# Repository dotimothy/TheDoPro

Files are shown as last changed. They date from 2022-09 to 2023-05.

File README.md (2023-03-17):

# TheDoPro: A  Simplistic Stereovision Camera
## UC Irvine 2022-2023 Senior Design Project
Members: Timothy Do, Daniel Jilani, Zaya Lazar, Harrison Nguyen
<br>
Advisor: Professor [Glenn Healey](https://engineering.uci.edu/users/glenn-healey)
<br> 
<br>
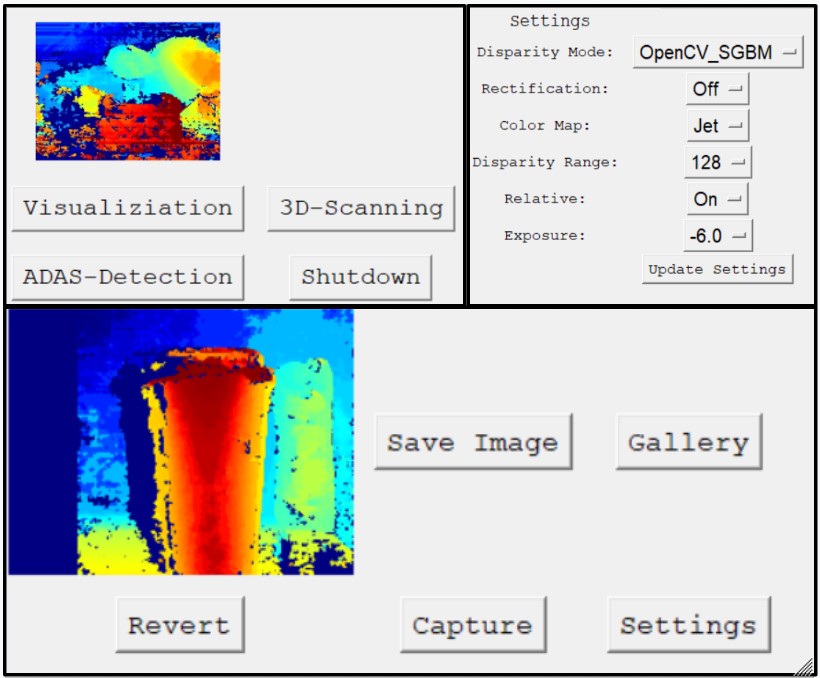
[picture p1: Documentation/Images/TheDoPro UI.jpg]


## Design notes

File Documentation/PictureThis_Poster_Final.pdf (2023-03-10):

# The Do-Pro: A Simplistic Stereo-Vision Camera

Timothy Do, Daniel Jilani, Zaya Lazar, Harrison Nguyen Professor Glenn Healey
Department of Electrical Engineering and Computer Science

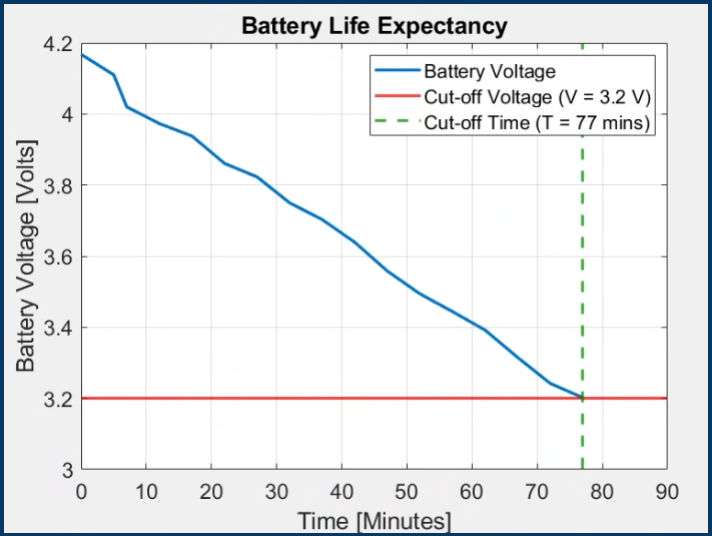
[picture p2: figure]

## Background

Humans have evolved with binocular vision to percieve depth [1]. This concept is applied to machines [2] in the form of SV, where two or more cameras take pictures of a scene and compute depth for technological applications. Some practical applications are 3-D scene reconstruction and Advanced Driving Assistance System (ADAS).

A simple SV camera is created by vertically aligning two embedded cameras separated by a baseline distance b and computing the disparity xL–xR between the two images captured by both cameras and mapping it to depth z (Fig. 1).

## Results

Hardware:
The Do-Pro was successfully assembled in its portable form factor. The battery life of the Do-Pro has a maximum expectancy of about 77 minutes (i.e., when the 3200 mAh battery drops from 4.2 V to 3.2 V).

Software:
The Do-Pro can generate relative visualizations of depth (Fig. 5). It was able to accurately measure depth from 1-4 feet with an accuracy of +/-1.5 inches (6% error). It can accurately reconstruct a 3-D point cloud and detect close-up objects around 1 feet away with 90% accuracy.

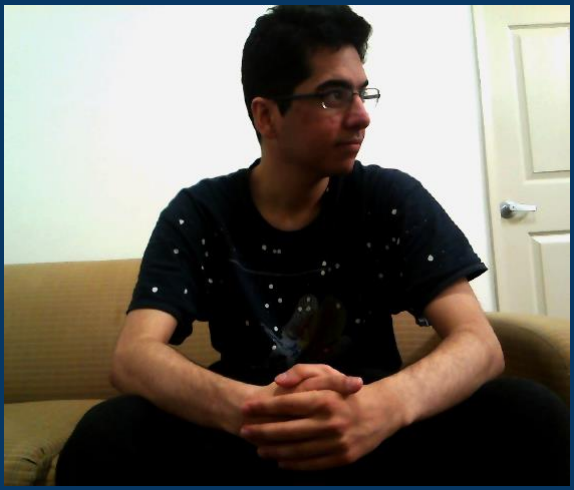
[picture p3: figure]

## References

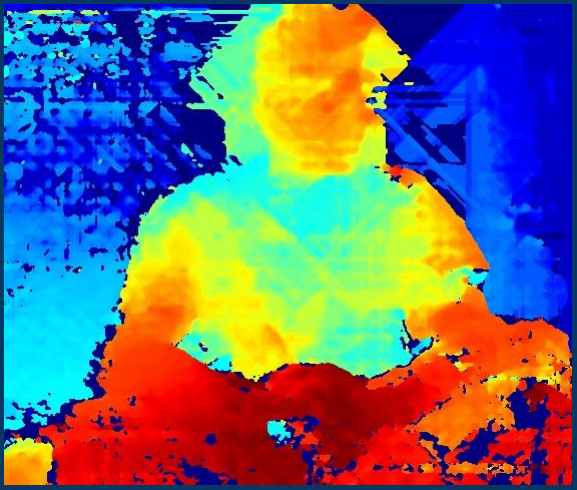
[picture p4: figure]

[1] F. Li (2014). Lecture 9 & 10: Stereo Vision. [PowerPoint]. Available: http://vision.stanford.edu/teaching/cs131_fall1415/lectures/lecture9_10_stereo_cs131. pdf
[2] B.K.P. Horn,, “Robot Vision”, Cambridge, MA: MIT Press, 1986, ch. 13.
[3] D. Scharstein, R. Szeliski and R. Zabih, "A taxonomy and evaluation of dense two-frame stereo correspondence algorithms," Proceedings IEEE Workshop on Stereo and
Multi-Baseline | Vision | (SMBV | 2001), | 2001, | pp. | 131-140, | doi:
10.1109/SMBV.2001.988771.

## Materials & Methodology

Hardware Design: 3-D Enclosure and Custom PCB
The 3-D enclosure replicates a digital camera for familiarity and ease of use. The custom PCB powers the cameras, buttons, LEDs, & touchscreen to a Raspberry Pi 4 using a boost converter topology with an 18650 battery cell (Fig. 2).

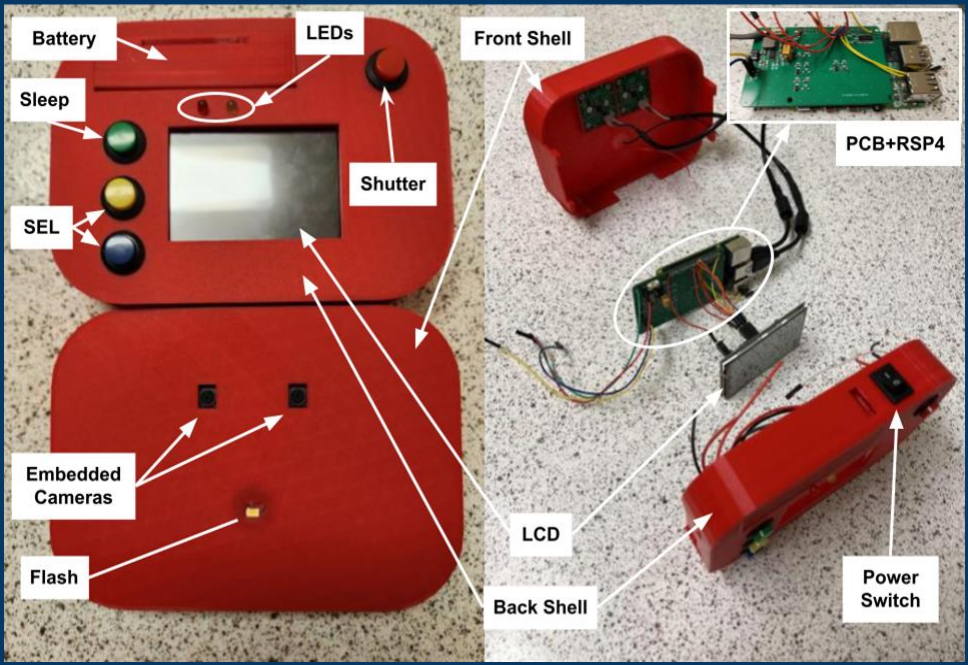
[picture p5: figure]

Software Design: User-Interface and Algorithms
The user interface (Fig. 3) was designed for configuring different visualizations of the disparity output. A specific rectification model was developed for calibrating the stereo pair. Multiple disparity algorithms [3] have been incorporated so users can tailor to their specific needs.

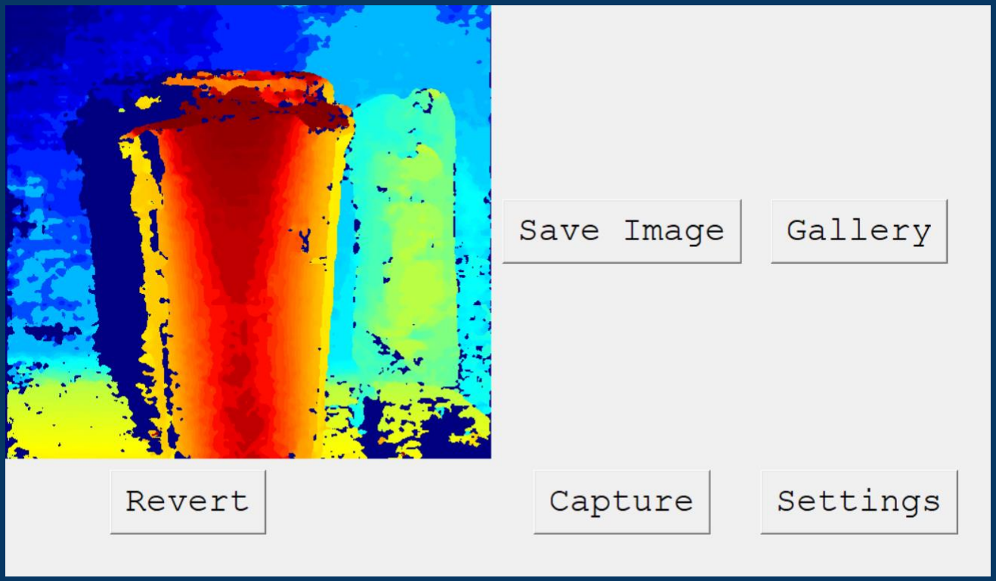
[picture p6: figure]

Applications: ADAS and 3-D Reconstruction
The Do-Pro can be used as an ADAS sysytem by K-Means clustering & segmenting the disparity output for detecting nearby objects. It can also be used for 3-D reconstruction by converting the disparity into depth to transform the scene into a point cloud.

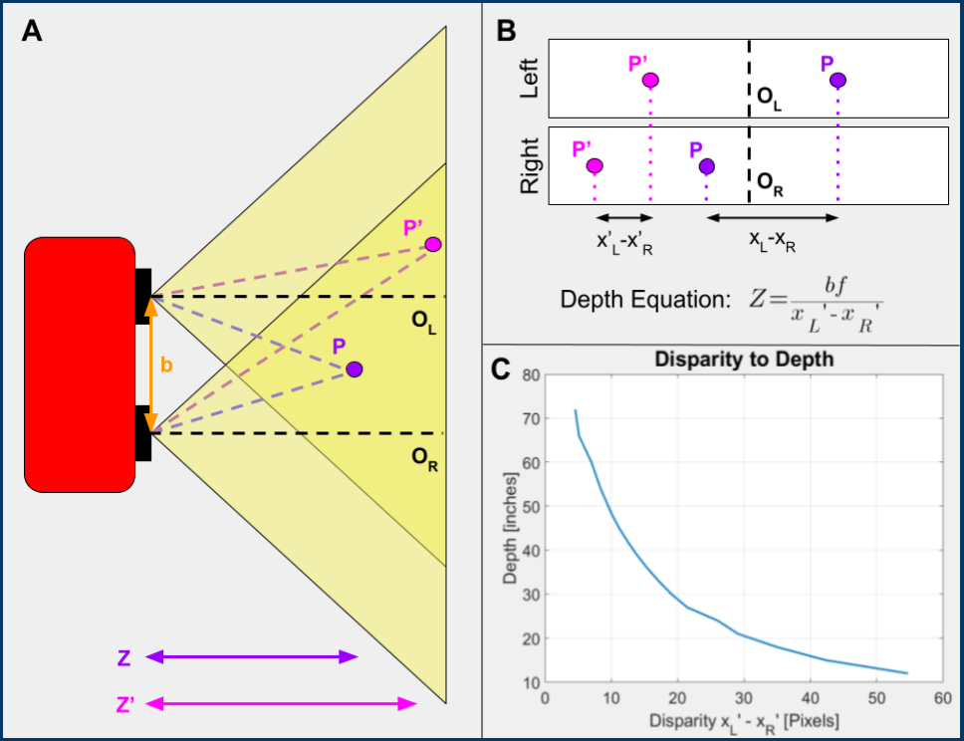
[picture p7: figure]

Figure 1. (A) SV camera imaging two scene points P and P’ located at depths Z and Z’ respectively. (B) Disparity between left and right images; closer scene points present greater disparities. (C) Empirically derived disparity to depth transform for the Do-Pro with a power regression model.

## Objectives

In this project, a portable stereo-vision (SV) camera, named The Do-Pro, was designed using off-the-shelf components to explore applications of depth perception. The Do-Pro aims to make SV technology more accessible and easy to use for unfamiliar scientists and hobbyists. The Do-Pro also provides a good introduction to computer vision and electrical engineering for K-12 students who are interested in STEM careers.

Figure 3. Touchscreen user interface and disparity of a coffee cup.

Figure 2. Components and connections of the camera.

Figure 4. Battery voltage under disparity computation load (~10 W).

Figure 5. Original image (left) vs. relative disparity map (right).

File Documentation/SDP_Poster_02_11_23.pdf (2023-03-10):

### Overview

Stereo vision is the extraction of depth in a scene from two or more images. In this project, an active stereo vision camera is designed with the ability to accurately extract depth from a scene for 3D-Scene Reconstruction and Object Detection.

### Deliverables

- Functional Stereo Vision Camera
- Active Stereo Implementation
- 3D Scene Reconstruction
- Object Detection System

### Background

Stereo vision cameras are specialized instruments designed to produce depth from at least two images. In active stereo vision, features are projected onto the scene which improves the disparity accuracy by making points in the scene more distinguishable.

### References

[1] D. Scharstein, R. Szeliski and R. Zabih, "A taxonomy and evaluation of dense two-frame stereo correspondence algorithms," Proceedings IEEE Workshop on Stereo and Multi-Baseline Vision (SMBV 2001), 2001, pp. 131-140, doi: 10.1109/SMBV.2001.988771.
[2] Q. Chang and T. Maruyama, "Real-Time Stereo Vision System: A Multi-Block Matching on GPU," in IEEE Access, vol. 6, pp. 42030-42046, 2018, doi: 10.1109/ACCESS.2018.2859445.
[3] F. Li (2014). Lecture 9 & 10: Stereo Vision. [Powerpoint]. Available: http://vision.stanford.edu/teaching/cs131_fall1415/lectures/lecture9_10_stereo_cs131.pdf

### Methodology

Hardware: Two embedded cameras are connected to a Raspberry Pi 4 for processing. A Custom PCB is used to connect the Pi, Buttons, LED, and LCD Touchscreen. Everything is housed within a portable 3D-printed enclosure.

Software: Several stereo matching algorithms are implemented for computing scene disparity with changeable parameters to control the disparity mapping.

# Project Progress

Hardware: | Software:

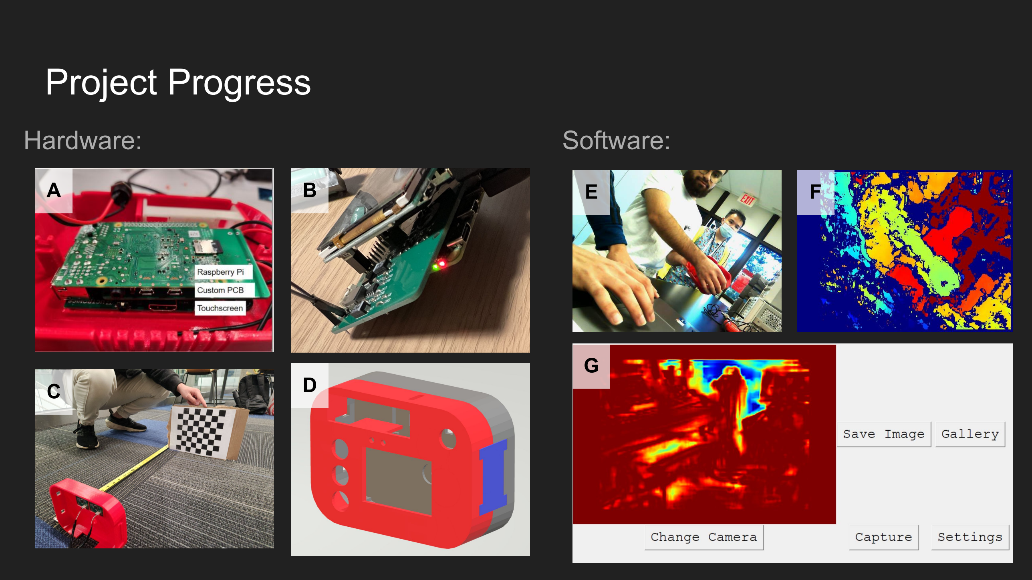
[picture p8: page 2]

A B

C D

E F

G

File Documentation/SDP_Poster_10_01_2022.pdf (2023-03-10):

# The Do-Pro: A Minimalistic Stereo Vision Camera

### Team: Timothy Do, Daniel Jilani, Zaya Lazar, Harrison Nguyen | Advisor: Dr. Glenn Healey

Background:

To perceive depth, two images of a scene must be observed at different points along a shared axis. Stereo vision cameras are specialized instruments designed to produce depth from at least two images. These cameras are specialized and expensive with state-of-the-art commercial cameras costing $500 and requiring a mount. In this proposal, we aim to produce a more affordable stereo vision camera designed for versatile applications.

A conceptual illustration of the proposed stereo vision camera. The camera is similar in style to most handheld digital cameras

Milestones:
- Milestone A - Develop simple stereo camera model and achieve functionality on breadboard
- Milestone B - Calibrate stereo-vision cameras
- Milestone C - Implement stereo vision processing, camera software mechanics, and PCB functionality Example of depth estimation on stereo vision image set.
S | F | W

Milestone A

| Milestone B
| Milestone C

Software Deliverable:

Hardware Deliverable:

High level wiring schematic of the proposed stereo vision camera system

References:
[1] A. Vij, “Stereo vision: How do 'terminators' see the world?,” Medium, 23-Mar-2021. [Online].
[2] B.K.P. Horn,, “Robot Vision”, Cambridge, MA: MIT Press, 1986, ch. 13.
[3] D. Scharstein, R. Szeliski and R. Zabih, "A taxonomy
and | evaluation | of | dense | two-frame | stereo
correspondence | algorithms," | Proceedings | IEEE
Workshop on Stereo and Multi-Baseline Vision (SMBV
2001), | 2001, | | pp. | 131-140, | doi:
10.1109/SMBV.2001.988771.

General Deliverables:
- Functional camera – 3D-printed chassis and manufactured PCB
- Auto-calibration
- Image & video Processing
- UI + touch screen + instruction manual
- ***Object tracking***

# Stereo-Vision Demonstration

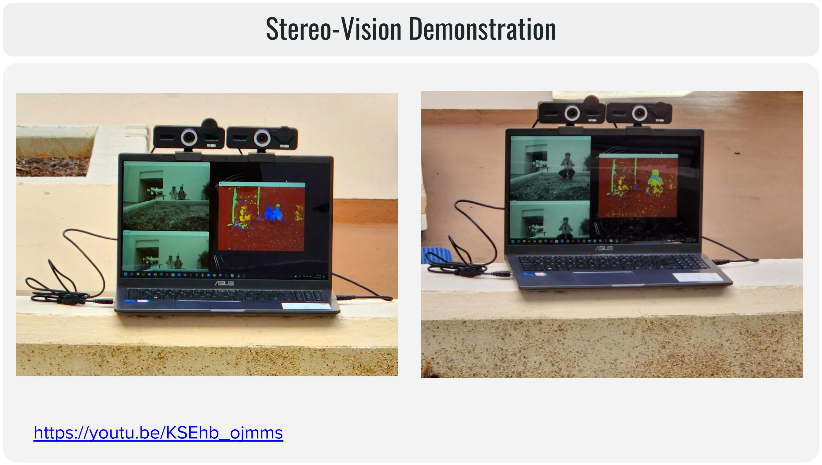
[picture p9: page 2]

# https://youtu.be/KSEhb_ojmms

# Estimated Expenses

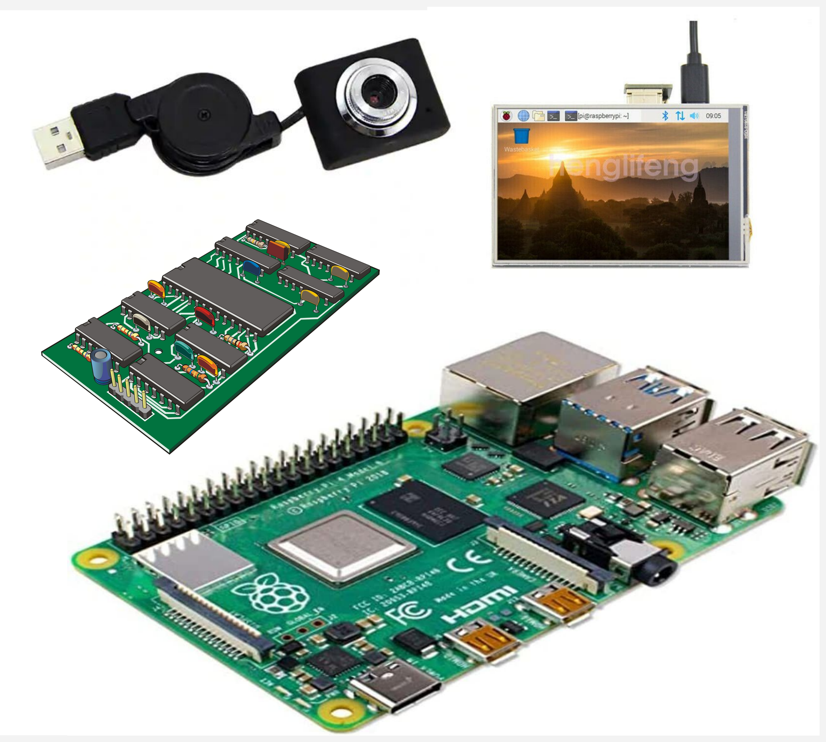
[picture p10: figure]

# Materials Expenses (Need to buy):

★ | Embedded Camera (x2) – $17.80
★ | Touchscreen Display – $36.99
★ | PCB Manufacturing – $25
★ | Miscellaneous Components – $18.04
★ | Vendors: Amazon, Digikey

# Required Expenses: ~$100

# Requested Funding: $175

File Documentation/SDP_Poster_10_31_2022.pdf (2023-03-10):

### Overview

Stereo vision is the analysis of depth in a scene from two or more images. For our project, we are designing a hand-held digital camera for stereo vision.

### Goals and Milestones

- Develop a compact stereo vision camera – as small as feasibly possible (Fall)
- Perform real-time stereo vision imaging for pictures and video (Fall)
- Utilize the camera for 3D printing and object tracking applications (Winter)

### Background

Stereo vision cameras are specialized instruments designed to produce depth from at least two images. These cameras are specialized and
expensive | with | state-of-the-art | commercial
cameras costing $500 and requiring a mount. In this proposal, we aim to produce a more affordable stereo vision camera designed for versatile applications.

### References

[1] D. Scharstein, R. Szeliski and R. Zabih, "A taxonomy and evaluation of dense two-frame stereo correspondence algorithms," Proceedings IEEE Workshop on Stereo and Multi-Baseline Vision (SMBV 2001), 2001, pp. 131-140, doi: 10.1109/SMBV.2001.988771.
[2] Q. Chang and T. Maruyama, "Real-Time Stereo Vision System: A Multi-Block Matching on GPU," in IEEE
Access, | vol. | 6, | pp. | 42030-42046, | 2018, | doi:
10.1109/ACCESS.2018.2859445.
[3] A. Islam, M. Asikuzzaman, M. O. Khyam, M. Noor-A-Rahim and M. R. Pickering, "Stereo Vision-Based 3D Positioning and Tracking," in IEEE Access, vol. 8, pp.
138771-138787, | 2020, | doi:
10.1109/ACCESS.2020.3011360.

### Methodology

Hardware: The hardware implemented consists of a custom PCB, Raspberry Pi, and two cameras in a 3D-Printed enclosure.

Software: The stereo matching algorithm described in [2] is implemented and vectorized for real-time computation of a image disparity map.

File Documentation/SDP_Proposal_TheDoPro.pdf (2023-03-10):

# The Do-Pro: A Minimalistic Stereo Vision Camera

# Proposed by Timothy Do, Daniel Jilani, Zaya Lazar, Harrison Nguyen

# Why care about depth?

# - In the near future, data will become one of the most important commodities in the world – industries and innovations will become significantly data-driven

# - Machine learning and image processing almost go hand-in-hand with significant applications in almost every field, such as autonomous vehicles

# - Creating a commercial camera that can segment an image into various depths will be highly valuable for machine learning applications in imaging

# - We want to generalize the technology and remove the need for specialized equipment

# Introduction

# - Cameras have become ubiquitous with various applications from iPhones to CC-TV cameras to dash cams

# - However, normal cameras by themselves do not have the capability to denote depth in an image

# - To quantify depth in an image, at least two cameras are required

# - Image processing methods exist to detect depth require complex models or very largely data-driven

- Lidar can be use in tandem with a camera to detect depth more accurately (i.e. iPhone XIV), but

# the technology is expensive

# Commercial Stereo Vision Cameras

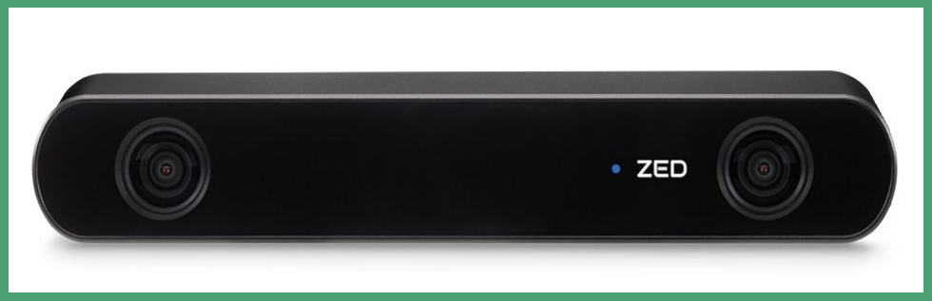
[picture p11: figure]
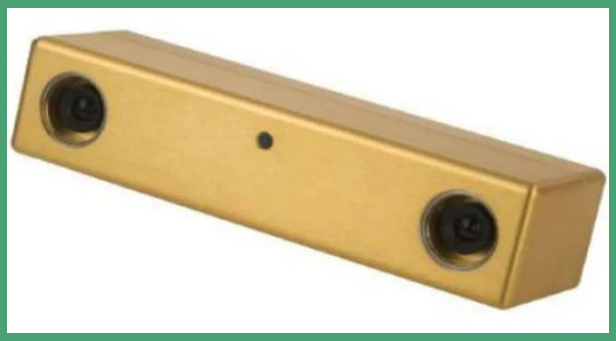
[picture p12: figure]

# - Bumblebee 2 / XB3

# - Discontinued - Varying price depending on seller

# - Zed 2

# - Price: $499 - State-of-the-art ■ Implements neural network for improved depth sensing and other spatial detection

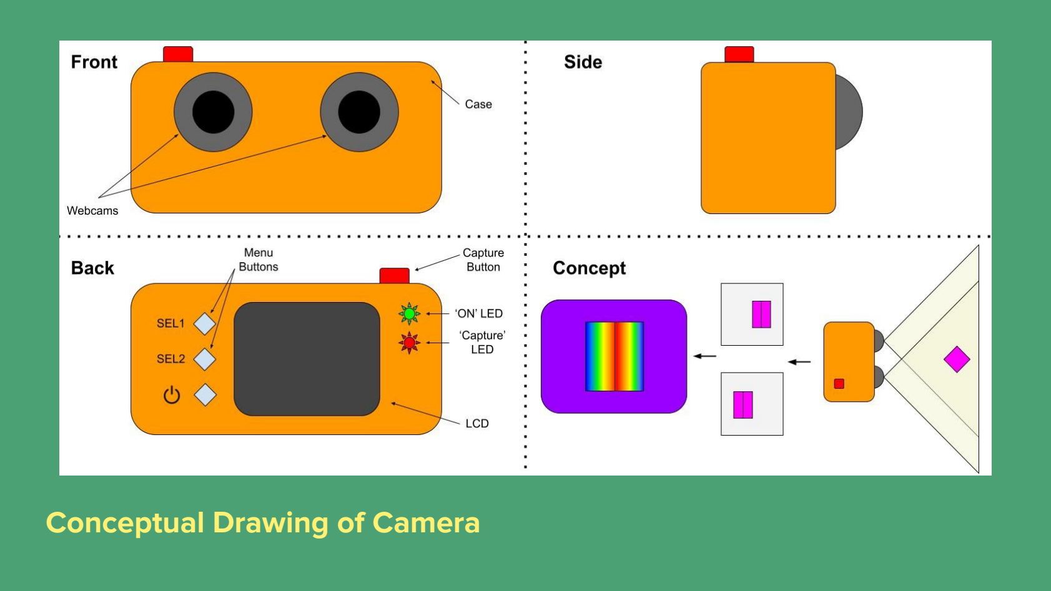
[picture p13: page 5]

# Conceptual Drawing of Camera

# Conceptual Design

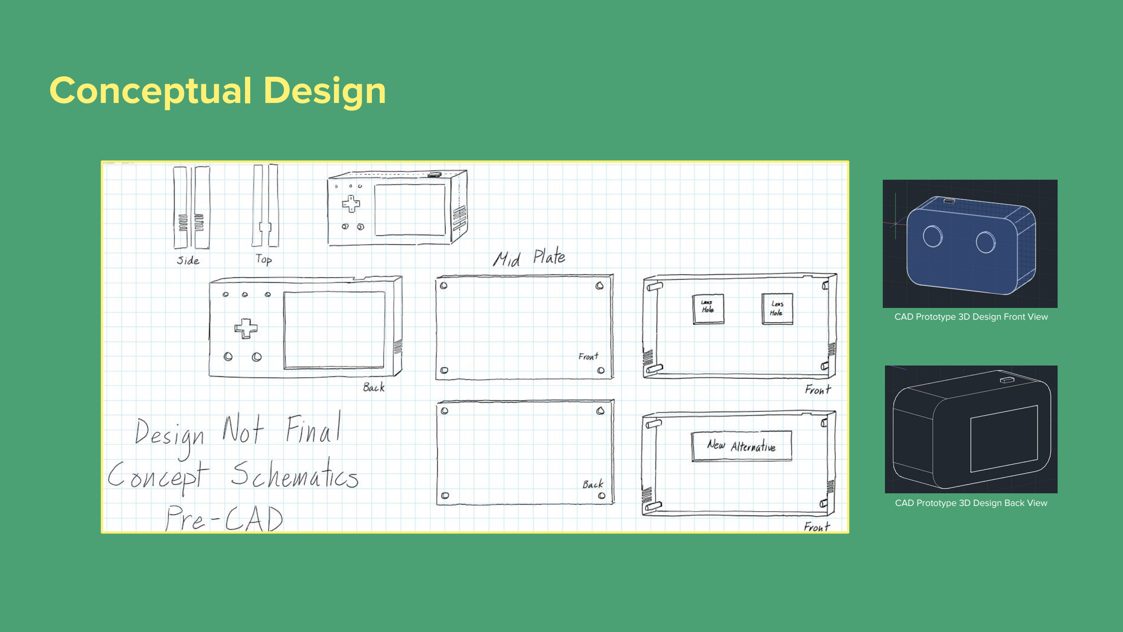
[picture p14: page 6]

CAD Prototype 3D Design Front View

CAD Prototype 3D Design Back View

# Concept Elaboration Updates

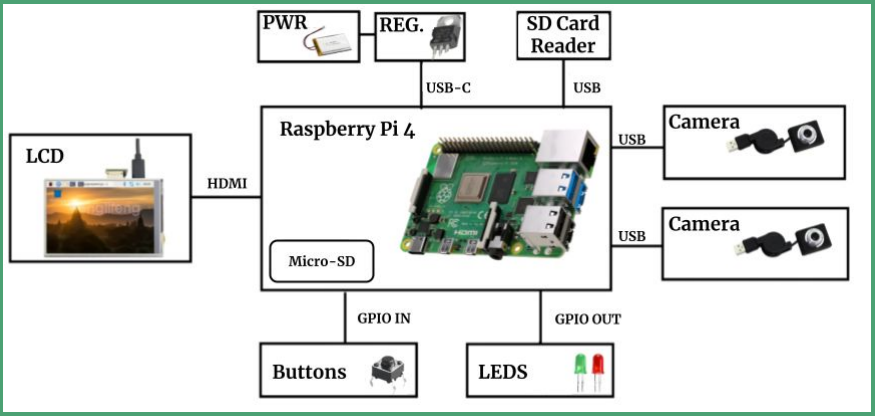
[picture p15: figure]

# High-level Wiring Schematic

# - Milestone A - Develop simple camera model

## - Design chassis for camera - Design wiring schematic for electronic components - Produce PCB and connect camera components - Test basic functionality - Optional: Adjustable distance between cameras

# - Milestone B - Calibrate stereo vision cameras

## - Test camera calibration outside of camera chassis - Implement camera calibration on raspberry pi with chassis - Implement procedure to calibrate cameras as a user function

# - Milestone C - Create depth heat map / 3D point cloud

## - In parallel with camera calibration, experiment with disparity map and 3D point cloud - Test display on LCD and create GUI

# Milestones

# Timeline

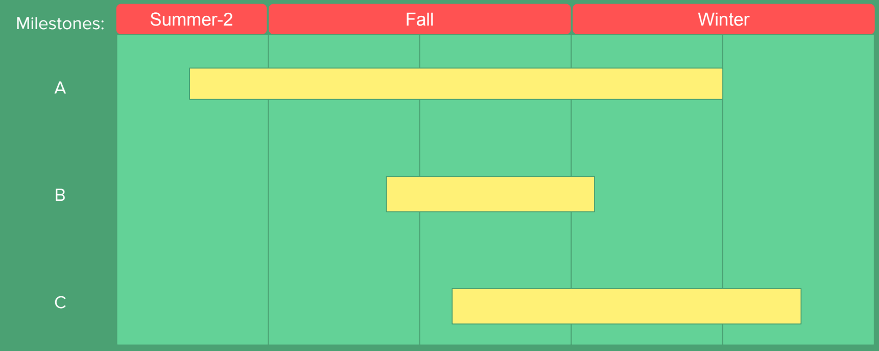
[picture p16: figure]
Milestones:; Summer-2; Fall; Winter

# Materials List

# - Regulator ICs - Various resistors and capacitors - Diodes - Fuse(s) - LCD Display - Custom PCB - Embedded Cameras (x2) - LEDs - Buttons - Capture Button - Raspberry Pi 4

# The Do-Pro: A Minimalistic Stereo Vision Camera

### Team: Timothy Do, Daniel Jilani, Zaya Lazar, Harrison Nguyen | Advisor: Dr. Glenn Healey

Background:

To perceive depth, two images of a scene must be observed at different points along a shared axis. Stereo vision cameras are specialized instruments designed to produce depth from at least two images. These cameras are specialized and expensive with state-of-the-art commercial cameras costing $500 and requiring a mount. In this proposal, we aim to produce a more affordable stereo vision camera designed for versatile applications.

A conceptual illustration of the proposed stereo vision camera. The camera is similar in style to most handheld digital cameras

Milestones:
- Milestone A - Develop simple stereo camera model and achieve functionality on breadboard
- Milestone B - Calibrate stereo-vision cameras
- Milestone C - Implement stereo vision processing, camera software mechanics, and PCB functionality Example of depth estimation on stereo vision image set.
S | F | W

Milestone A

| Milestone B
| Milestone C

Software Deliverable:

Hardware Deliverable:

High level wiring schematic of the proposed stereo vision camera system

References:
[1] A. Vij, “Stereo vision: How do 'terminators' see the world?,” Medium, 23-Mar-2021. [Online].
[2] B.K.P. Horn,, “Robot Vision”, Cambridge, MA: MIT Press, 1986, ch. 13.
[3] D. Scharstein, R. Szeliski and R. Zabih, "A taxonomy
and | evaluation | of | dense | two-frame | stereo
correspondence | algorithms," | Proceedings | IEEE
Workshop on Stereo and Multi-Baseline Vision (SMBV
2001), | 2001, | | pp. | 131-140, | doi:
10.1109/SMBV.2001.988771.

General Deliverables:
- Functional camera – 3D-printed chassis and manufactured PCB
- Auto-calibration
- Image & video Processing
- UI + touch screen + instruction manual
- ***Object tracking***

# Estimated Expenses

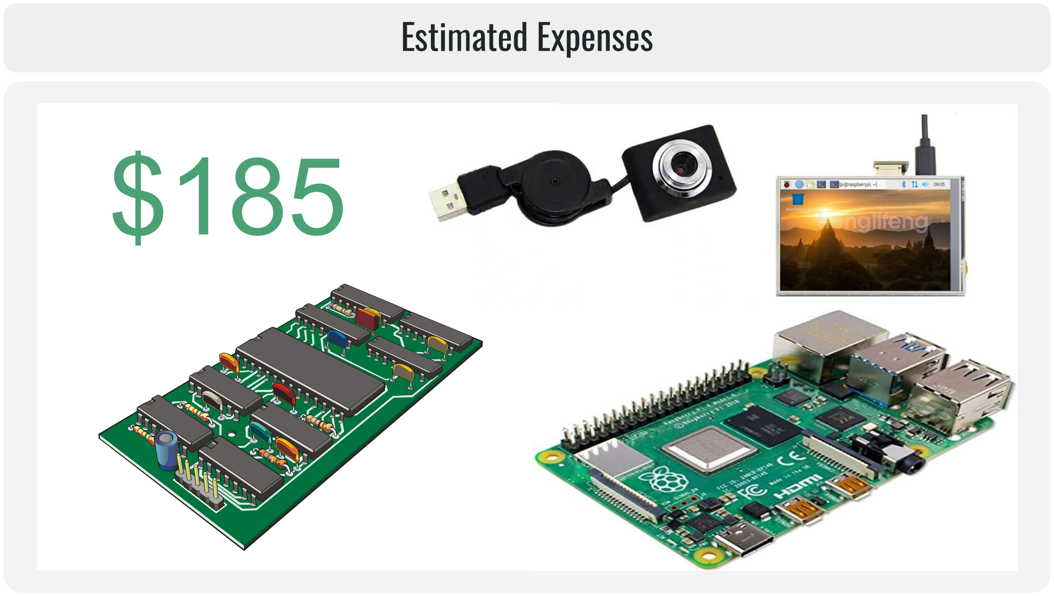
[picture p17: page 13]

$185

# Stereo-Vision Demonstration

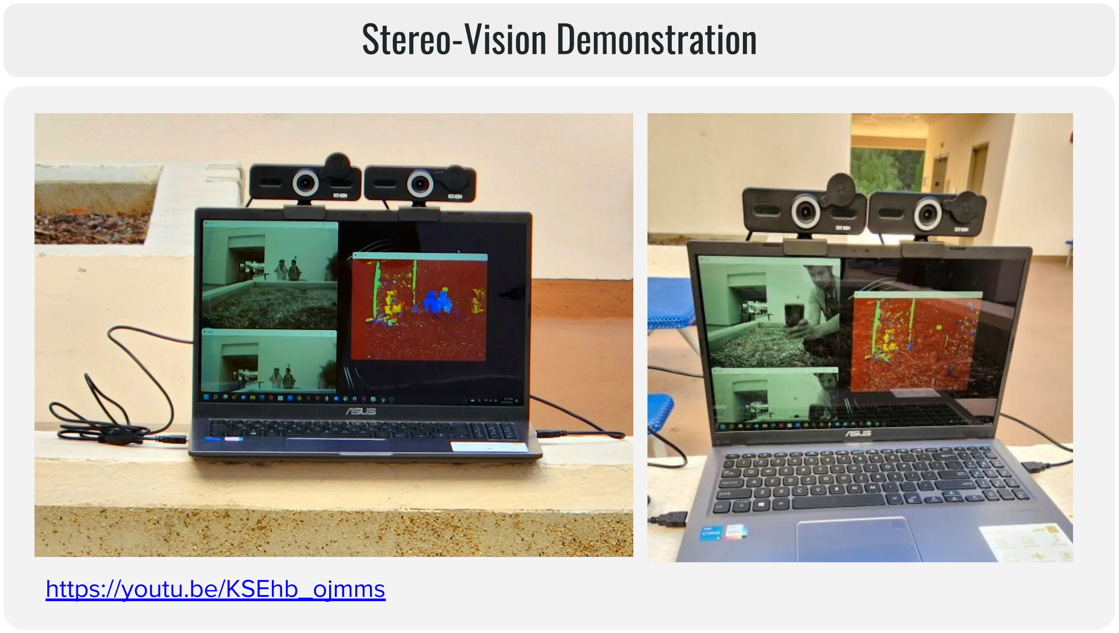
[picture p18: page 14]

# https://youtu.be/KSEhb_ojmms

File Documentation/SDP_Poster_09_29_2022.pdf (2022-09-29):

# The Do-Pro: A Minimalistic Stereo Vision Camera

### Team: Timothy Do, Daniel Jilani, Zaya Lazar, Harrison Nguyen | Advisor: Dr. Glenn Healey

Background:

To perceive depth, two images of a scene must be observed at different points along a shared axis. Stereo vision cameras are specialized instruments designed to produce depth from at least two images. These cameras
are | specialized | and | expensive | with | the | most
state-of-the-art commercial cameras costing $500 and a mount. In this proposal, we aim to produce a more affordable stereo vision camera designed for versatile applications.

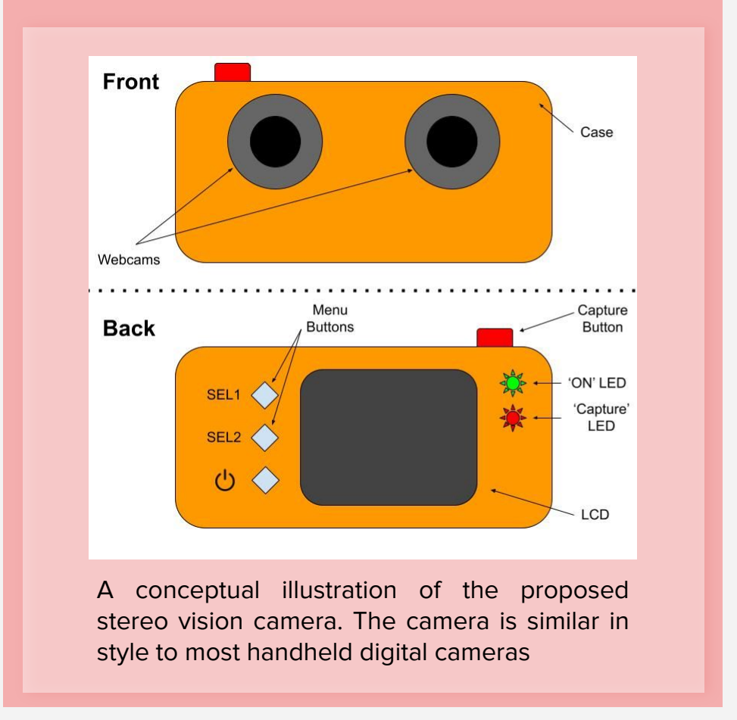
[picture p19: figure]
style to most handheld digital cameras

A conceptual illustration of the proposed stereo vision camera. The camera is similar in

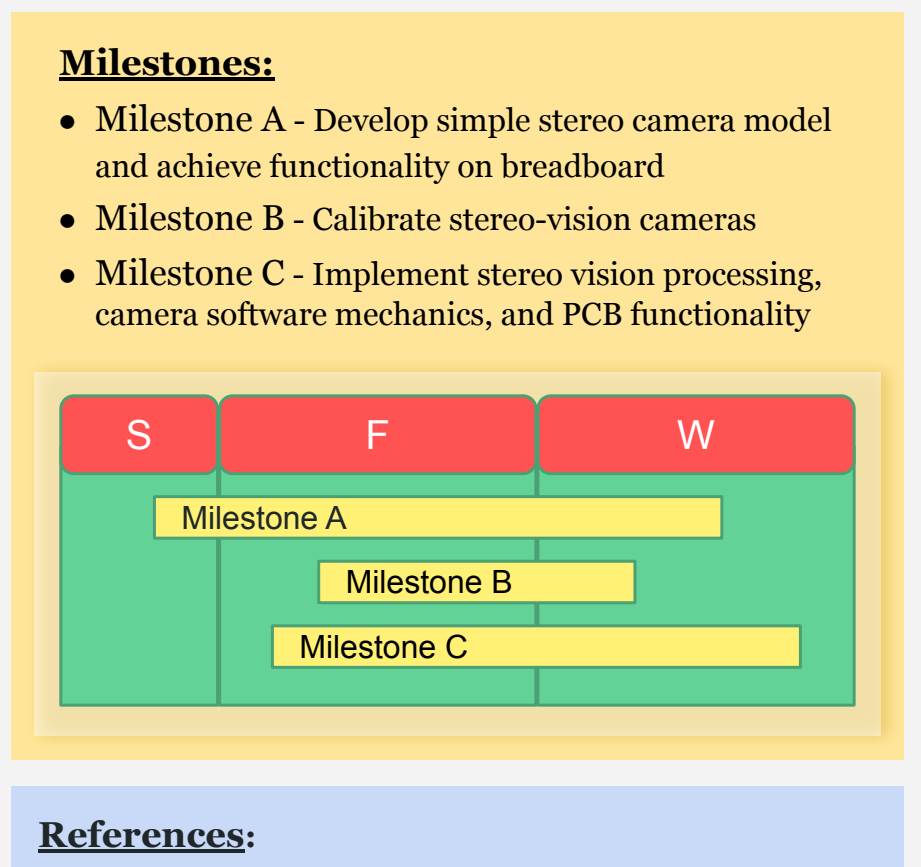
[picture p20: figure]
Milestones:; and achieve functionality on breadboard; Milestone A; Milestone B; Milestone C; References:

- Milestone A - Develop simple stereo camera model
- Milestone B - Calibrate stereo-vision cameras
- Milestone C - Implement stereo vision processing, camera software mechanics, and PCB functionality

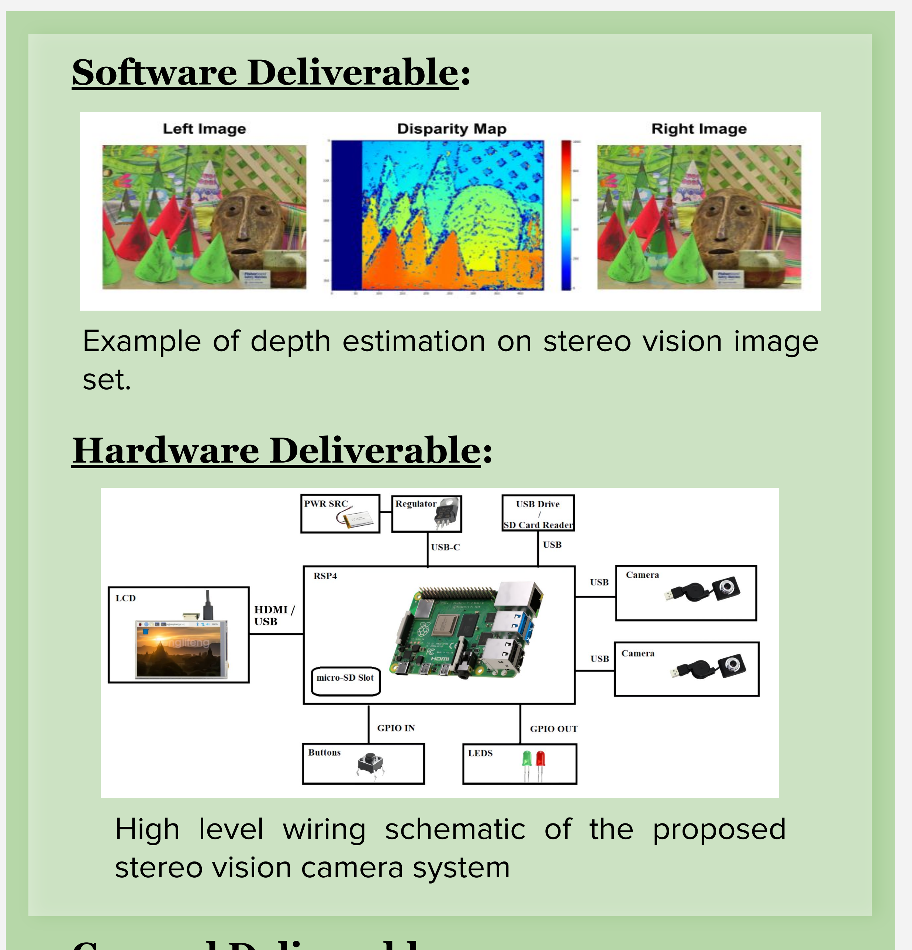
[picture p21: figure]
set.; Software Deliverable:; Hardware Deliverable:; stereo vision camera system

Example of depth estimation on stereo vision image

High level wiring schematic of the proposed
[1] A. Vij, “Stereo vision: How do 'terminators' see the world?,” Medium, 23-Mar-2021. [Online].
[2] G. Healey, “EECS 101 Chapter 13”, University of California, Irvine. [Powerpoint].
[3] D. Scharstein, R. Szeliski and R. Zabih, "A taxonomy
and | evaluation | of | dense | two-frame | stereo
correspondence | algorithms," | Proceedings | IEEE
Workshop on Stereo and Multi-Baseline Vision (SMBV
2001), | 2001, | | pp. | 131-140, | doi:
10.1109/SMBV.2001.988771.

General Deliverables:
- Functional camera – 3D-printed chassis and manufactured PCB
- Auto-calibration
- Image & video Processing
- UI + instruction manual
- ***Object tracking***

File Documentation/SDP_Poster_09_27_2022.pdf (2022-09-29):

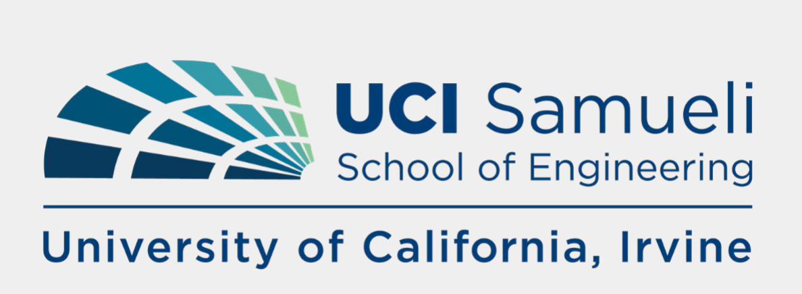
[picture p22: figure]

# The Do-Pro: A Minimalistic Stereo Vision Camera

Team: Timothy Do, Daniel Jilani, Zaya Lazar, Harrison Nguyen | Advisor: Dr. Glenn Healey

Background:
To perceive depth, two images of a scene must be observed at different points along a shared axis. Stereo vision cameras are specialized instruments designed to produce depth from at least two images. These cameras are specialized and
expensive | with | the | most | state-of-the-art
commercial cameras costing $500 and a mount. In this proposal, we aim to produce a more affordable stereo vision camera designed for versatile applications.

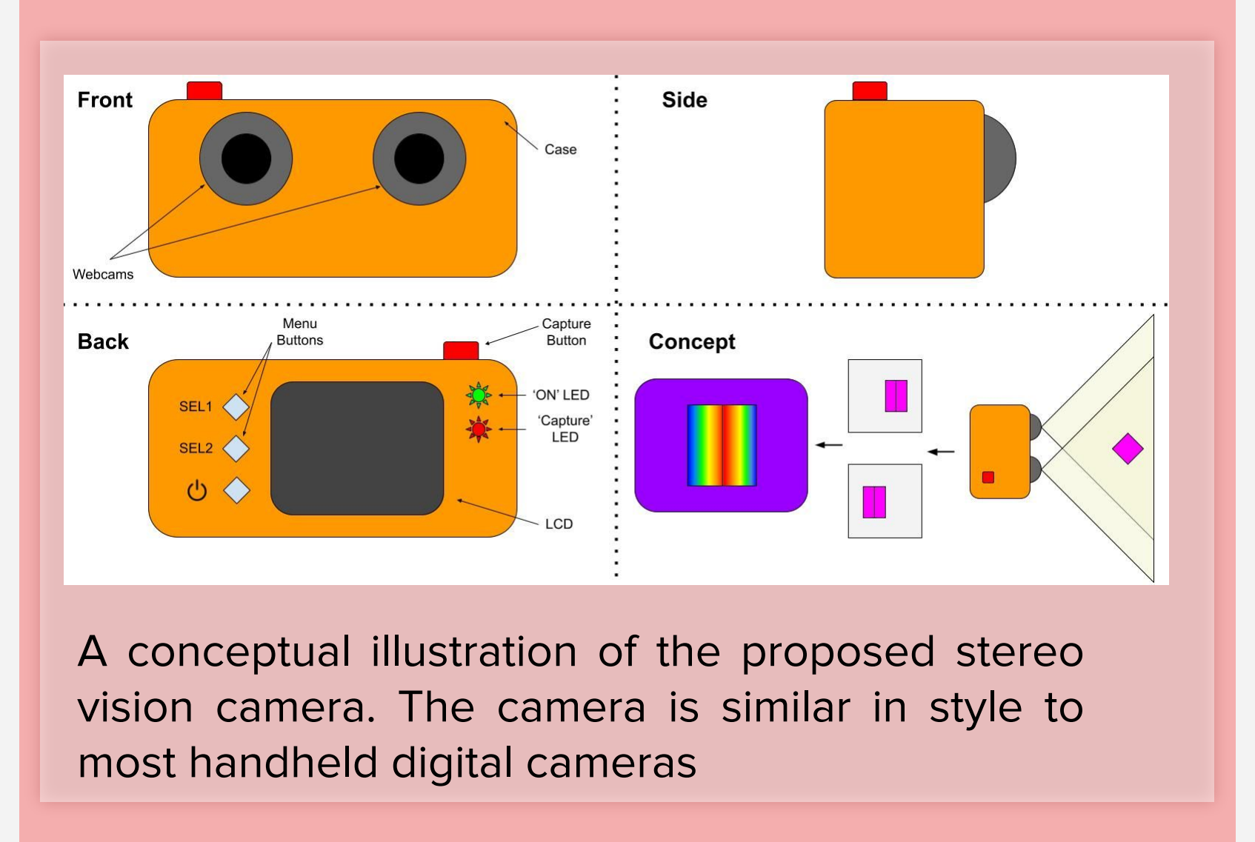
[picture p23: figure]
most handheld digital cameras

A conceptual illustration of the proposed stereo vision camera. The camera is similar in style to

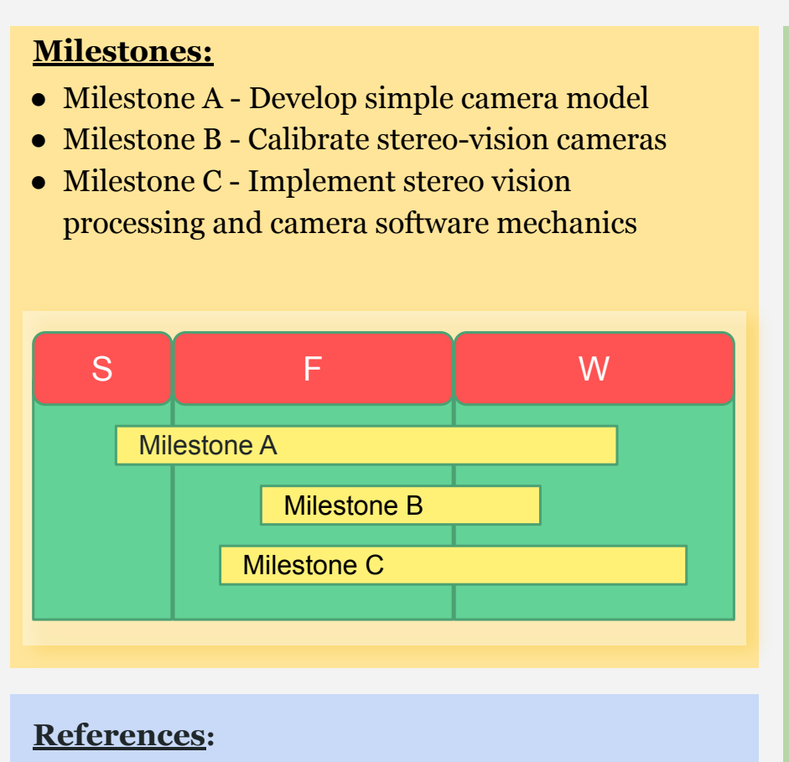
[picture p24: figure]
Milestones:; ● Milestone C - Implement stereo vision processing and camera software mechanics; Milestone A; Milestone B; Milestone C; References:

- Milestone A - Develop simple camera model
- Milestone B - Calibrate stereo-vision cameras

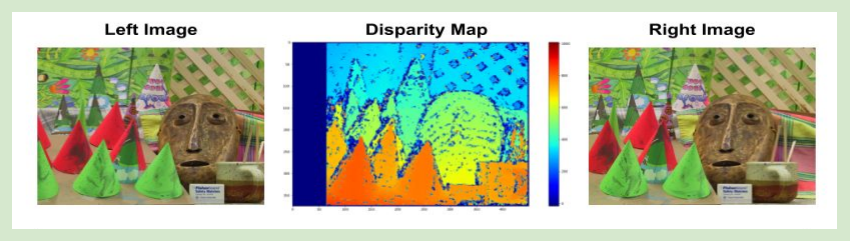
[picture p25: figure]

Example of depth estimation on stereo vision image set.

Software Deliverable:

Hardware Deliverable:


High level wiring schematic of the proposed stereo vision camera system
[1] A. Vij, “Stereo vision: How do 'terminators' see the world?,” Medium, 23-Mar-2021. [Online].
[2] G. Healey, “EECS 101 Chapter 13”, University of California, Irvine. [Powerpoint].
[3] D. Scharstein, R. Szeliski and R. Zabih, "A taxonomy
and | evaluation | of | dense | two-frame | stereo
correspondence | algorithms," | Proceedings | IEEE
Workshop on Stereo and Multi-Baseline Vision (SMBV
2001), | 2001, | | pp. | 131-140, | doi:
10.1109/SMBV.2001.988771.

General Deliverables:
- Functional camera – 3D-printed chassis and manufactured PCB
- Auto-calibration
- Image & video Processing
- UI + instruction manual
- ***Object tracking***

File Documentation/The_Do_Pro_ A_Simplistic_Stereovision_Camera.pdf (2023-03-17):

# The Do-Pro: A Simplistic Stereo-vision Camera

Timothy Do¹

, Daniel Jilani¹

, Zaya Lazar¹

, Harrison Nguyen¹

1 Department of Electrical Engineering and Computer Science, University of California, Irvine, Irvine, USA

Abstract—To make computer vision technology more accessible to small consumers such as scientists, hobbyists, and students, the Do-Pro is proposed as a simple and affordable depth perception camera. Compared to state-of-the-art LIDAR systems that cost tens of thousands of dollars with few examples of mass manufacturing, the Do-Pro boasts a $320 price tag made up of exclusively off-the-shelf components. The Do-Pro can accurately perceive depth from 1-3 feet with approximately 1.5 inches (6%) error, sufficient for ADAS and 3D Scanning applications.

Index Terms—computer vision, embedded systems, image processing, internet-of-things, stereo-vision.

I. INTRODUCTION
S

TEREO vision cameras are a type of specialized camera that observe a scene from at least two perspectives to extract the depth in a scene. They are popularly employed in problems involving object tracking/detection and 3D reconstruction. Islam et al. [1] developed a stereo vision system for modeling human movement in a 3D-space set-up with two aligned and parallel Go-Pro cameras separated by 1 meter. Wong et al. [2] investigated a navigation aid system using stereo vision that enabled blind participants to understand the distance, size, and movement of obstacles. Achmed et al. [3] proposed a novel stereo-matching algorithm and demonstrated the capability of stereo vision to reproduce 3D scenes using point clouds. These publications show that stereo vision can be a versatile tool for scientists and researchers, but often require complex, technical, problem-oriented configurations that limit the accessibility of these technologies outside of the computer vision community. The Do-Pro is designed as an inexpensive and generic stereo-vision camera to expand the accessibility of this technology.

A. Stereo-Vision
A typical stereo-vision setup (Fig. 1A) consists of two identical cameras on the same longitudinal (z) and vertical (y) axis separated by a set lateral distance. The concept of stereovision is to capture a scene from different lateral perspectives, then compute the displacement of each point between the two scenes (Fig. 1B) known as disparity [4]. Depth can then be calculated with optical geometry and intrinsic properties of the camera model (Fig. 1C). From a geometric point in the scene, the governing equation to calculate depth is

Z =

bf
x

′
L − x

′
R

(1)

where Z is the perceived depth, b is the baseline lateral distance between the two cameras, f is the intrinsic focal


Fig. 1: The Do-Pro Stereo-Vision Concept. (A) Camera capturing scene points P and P’ located at depths z and z’.
(B) Disparity of point P and P’ in the left and right images.
(C) Mapping disparity to depth.

length of the camera, and x

′
l

and x

′
r

are the horizontal
pixel locations from the left and right images respectively. To generate a depth map, disparity is calculated at all pixel locations shared by the two scenes and then the equation is applied, given that b and f are constants.
B. Stereo Matching Algorithms

To compute depth, the pixel disparity between the images is computed using a stereo-matching algorithm which forms disparity maps. Rule-based stereo matching algorithms can be split into two types, namely local and global matching. Local matching algorithms are window-based techniques that minimize the cost function of disparity in order to compute the disparity map [5]. Global matching algorithms attempt to find a function of disparity that minimizes the energy of the agreement between two images globally and applies a regularization term to smooth the disparity map [5]. Overall, global matching methods provide higher accuracy than local matching methods but require more complex implementations, higher run times, and computational intensity [6]. Both local and global block-matching methods were implemented into the camera. Still, the best overall method for stereo-matching was a hybrid method implemented by OpenCV called the ”Semi-Global Block Matching algorithm”.

II. MATERIALS & METHODOLOGY

A. System & Parts Overview
The software and hardware systems work in conjunction with each other to achieve the functionalities of the Do-Pro. As shown in Figure 2, the hardware system of the Do-Pro compacts a set of embedded webcams to take sets of images with a user interface. The Python-based platform computes the depth map from the image pair and renders various visualizations that can be saved to a gallery for later viewing. The platform is hosted on a git repository [7] to employ version control across multiple operating systems.


Fig. 2: High Level Project Overview

After finalizing the high-level system requirements, the hardware system is assembled with off-the-shelf components, totaling to an amount of approximately $320 (MSRP; $425 with markups). The components were chosen based on cost, availability, and quality. The most integral components of the Do-Pro are:
- Raspberry Pi 4 (4GB) - Control and computing unit for basic camera functionality and image processing
- UTRONICS Touchscreen Display - Graphical interface with user input control and image viewing
- Arducam 8 MP Embedded USB Camera (x2) - Dual lens and sensor used to capture two images simultaneously at 1920x1080p resolution
- 18650 Battery Cell - Rechargeable system power supply
B. Hardware

The main hardware deliverables for the Do-Pro project are the 3D-printed enclosure and the custom PCB that connects the stereo-vision system. The enclosure is designed to secure all components into a compact form factor.
1) Custom PCB: The custom PCB is designed in Altium Designer with RoHS-compliant components. The schematic shown in Figure 3 depicts the sub modules and connections that are implemented in the PCB. The PCB connects power to all components, interfaces the touch screen and Raspberry Pi, implements low-battery monitoring, and most importantly minimizes the space required to perform these operations.


Fig. 3: Custom PCB Schematic

One notable feature of our PCB is that it utilizes a switchedmode boost converter for power delivery. This topology provides more power efficiency for converting 3.6V to 5.1V ( 90-95%) compared to linear regulators ( 60-70%) [8]. Additionally, the Raspberry Pi does not switch any load, including LEDs. We followed electronics best practices by switching loads via MOSFETS instead of GPIO pins. The custom PCB is a two-layer board, and the team paid special attention to the data sheet layout recommendations for implementation.
2) Enclosure: The enclosure is designed in Auto-CAD and 3D-printed using the Creality Ender 3 Pro. The design philosophy was to secure all the components through easy assembly but also provide ease of access to the electronics for troubleshooting and/or upgrading. The design focuses on optimizing the human interface for comfort and ease of use. The material used in the printing process was polyethylene terephthalate glycol (PETG) because of its impact durability and heat resistance. It is also a cost-effective material for prototyping and does not have any special requirements during the printing process (e.g., heated enclosure or fume extractor).


Fig. 4: Camera Housing CAD Model

3) Camera Calibration: To ensure that the disparity is properly computed, the position of the cameras must be along the same vertical (y) and longitudinal (z) axis. In regards to equation (1), b and f must stay constant. The depth equation is rearranged to solve for bf.

bf = Z(x

′
l − x

′
r
) | (2)

With our stereo system, a uniform checkerboard pattern is placed in front of the cameras (see Fig. 5). A checkerboard pattern exhibits distinct features in the edges of the grid to match points of correspondence. The cameras are fixed at a stationary position and take a sequence of 50 image pairs, where the checkerboard pattern is oriented and translated over different parts of the frame.
Afterwards, the image pairs are passed through MATLAB’s stereo camera calibrator app [9], estimating the intrinsic parameters of our stereo-system for remapping points that violate equation (2). The intrinsic parameters are included in our pipeline to rectify the image before the disparity is computed.


Fig. 5: Scene for MATLAB Checkerboard Calibration

4) Power Regression Model: A power regression model was created to estimate depth from raw disparity output. A flat object (e.g, a pillow) is placed in front of the cameras at a measured distance. Afterward, the disparity map is computed and the output at the center of the object is recorded. The process is repeated for increments of 3 inches from 1-3 feet. The data is finally passed through Microsoft Excel to create a power regression in the form:

Z = α(x

′
l − x

′
r

)

β
(3)
C. Software
1) Algorithms: Several algorithms were implemented on the Do-Pro to perform stereo-matching such as the multiblock matching algorithm proposed by Change and Maruyama [10]. However, here only the best algorithm, semi-global block matching (SGBM) [11], will be explained. To begin, all stereo-matching algorithms require a cost function C(·) which inversely measures the similarity of two image points. By making disparity a parameter of the cost function, the corresponding disparity of each image pixel can be computed by minimizing the cost function. However, flukes can easily occur in the minimization of the cost function resulting in incorrect disparities hence penalty terms are added to increase the cost for differences in the disparity between neighboring pixels. By combining the cost function and penalty terms, the energy function is created:

E(D) =X

p

[C(p, dp) + X

q∈Np

(P11{|dp − dq| = 1}

+ P21{|dp − dq| > 1})]

(4)

where D is the disparity map, dp and dq are the disparities of pixel p and q, P1 and P2 are the penalty weightings, and 1 is the indicator function. By minimizing the energy function with respect to the disparity map, a smooth and accurate disparity map is computed. This algorithm is the semi-global matching (SGM) algorithm but can be extrapolated to the SGBM algorithm by extrapolating the equation to compare blocks of pixels instead of individual pixels.
2) User Interface: The Do-Pro incorporates both a touchscreen and a physical button interface. Various touchscreen interfaces (see Fig. 6) are designed in python Tkinter, allowing users to operate the Do-Pro using touchscreen tiles. On the upper left, users have the option to select between the various depth application modes of the Do-Pro. After selecting a mode, a visualization like the bottom will appear, with tiles to capture depth, save images, view gallery, and access settings. The settings, shown in the upper right, allow the user to adjust disparity, rectification, camera exposure, etc.


Fig. 6: Various Touchscreen User Interfaces.

The physical button layout is designed for users who want a more traditional photography experience. The inputs available are Sel1 (toggling between cameras), Sel2 (Settings), Capture (for capturing the disparity), and Power (On/Off). All inputs are connected to the Raspberry Pi in a pull-up configuration. The Raspberry Pi reads the button inputs via the RPi.GPIO Python library. The digital logic for the Do-Pro button inputs is mapped to functions of the touchscreen interface.
3) Applications: For visualization, the jet colormap is applied to the disparity, where close objects are red and farther objects are bluer. Aside from depth visualization through a heat map, The Do-Pro features pipelines for ADAS (Advanced Driving Assistance) and 3D Scanning.
For ADAS detection, the Do-Pro simultaneously detects close objects and alerts the user by flashing the LEDs rapidly. The Do-Pro computes the disparity colormap (size MxN) and applies K-Means clustering (with K=3) to distinguish regions that are ’far’, ’close’ and ’in-between’. Afterward, a relative color (R,G,B) & size threshold (larger than 25% of image) is applied to detect if objects are close to the user. A cluster C is classified as close if conditions (5) & (6) are met:
|255 − R| ≥ 100 ∧ R ≥ 1.3 ∗ B | (5)
Size{C} ≥ 0.25 ∗ M ∗ N | (6)

For 3D scanning, the Do-Pro first generates the depth map from the disparity using the power regression model described in equation (3). Afterward, a 3D point cloud is reconstructed by superimposing the depth dimension onto the original left image. Finally, the point cloud is voxel downsampled and passed onto Open3D to generate an STL Triangle Mesh via the alpha shape method [12]. Since the Raspberry Pi doesn’t support OpenGL, the Do-Pro transfers the stereo-pairs of images via TCP sockets to a workstation to run Open3D’s visualizer and convert it into an STL file for 3D printing.

III. RESULTS

A. Hardware


Fig. 7: Camera Exterior (Left), Interior Layers (Right)

To analyze the current design of the enclosure, the design, while larger than the team had expected, was good, but not without flaws. The enclosure was durable and the components met at the desired symmetric faces and planes. Though the design was intended for organized fitment, we realized in hindsight, that some wired connections required more leeway. The video feed between the LCD screen and the Raspberry Pi now protrude from the enclosure. We understand that the sizing error margins of the enclosure structure need to be increased, and some of the structure sections needed to be rearranged and modified overall to better fit the electrical hardware components. After taking various notes of this prototype, future development should presumably be smoother as core fitment issues have been determined. Upon camera assembly, we have opted for 2 fully assembled components Fig. 7). The front, in particular, was determined to be an outstanding part, fitting the lenses perfectly, making for easier camera calibrations. Additionally, a flash LED was added for improvements in picture taking quality. This LED provided consistent lighting which supported the software systems. Both the cameras and the LED were connected to the Raspberry Pi and are securely fitted to this front enclosure. On the other hand, the back enclosure held the user interactive features. This half includes a removable slot for power supply replacements, input control buttons, the LCD screen for UI optical viewing, and the power switch.
After finalizing the camera assembly, we tested its battery life. We installed a fully-charged (4.2V) lithium-ion battery with a capacity of 3200mAh and ran the OpenCV disparity calculations while monitoring the battery voltage. The camera lasted 77 minutes before reaching the cut-off voltage that we set in software (See Fig. 8). We chose 3.2V as the cut-off voltage for the lithium-ion cell as it is a conservative cut-off to prevent the battery from over discharging.


Fig. 8: Battery Voltage under Disparity Load (∼10W)

B. Software

Two metrics can be measured in the disparity algorithm of The Do-Pro: depth accuracy and relative depth perception. We also present the calculation of the power regression model over a feasible range for 3D scanning purposes and visually compared different pipelines for depth perception.

1) Power Regression Model: For the power regression model, the disparity to depth relationship falls closely to the governing stereo equation (1). We decided to use OpenCV’s SGBM disparity algorithm to retrieve the power regression model. Notice that measured depth (Zm) has an inverse relationship with disparity (x

′
l − x

′
r

), as shown in Table I:

TABLE I: Measured Depth vs Computed Disparity

′ ′ x −x (px) r l | Zm (in.) | ′ ′ x −x (px) r l | Zm (in.)
172.375 | 3 | 29.0625 | 21
93.4375 | 6 | 26 | 24
70.4375 | 9 | 21.4375 | 27
54.6875 | 12 | 19.0625 | 30
42.3125 | 15 | 17.125 | 33
34.9375 | 18 | 15.375 | 36

Based on the curve of best-fit (plotted in Fig. 9), the model presents a high correlation between depth and disparity, with an R² = 0.9919. From the power regression model, it was found that α = 616.33, β = 1.011, & to fit into eq. (3), which becomes:

Z = 616.33(x

′
l − x

′
r

)

−1.011 | (7)


Fig. 9: Power Regression Fit Along Depth-Disparity

2) Depth Accuracy: For determining depth accuracy, we tested our power regression model with a different object (e.g, a mug) and measured the error of the perceived depth (Zp) from 1-3 ft. The tabulated results are shown in Table II, with an average percent error of 6.2% (1.5 inches):

TABLE II: Measured Depth vs Perceived Depth

Zm (in.) | Zp (in.) | Error (%)
12 | 10.6932 | 10.89
18 | 17.909 | 0.506
24 | 23.512 | 2.033
30 | 31.406 | 4.687
36 | 40.608 | 12.8
3) Visualization Results: For an ideal scene where lighting across the scene is bright and uniform, the Do-Pro performs exceptionally well at computing depth. In Figure 10, the original image and its depth map display an extremely pleasing visual of depth. To achieve this, histogram equalization was applied to the disparity map to spread out the depth information and make it more apparent. In addition, the depth map and original image could be converted into a triangle mesh or applied to ADAS clustering pipeline for detection (with a 90% success rate).


Fig. 10: Input and Outputs For Different Applications: Input (Top Left), Disparity Map (Top Right), 3D Triangle Mesh (Bottom Left), ADAS Clustering (Bottom Right)

IV. SUMMARY
The Do-Pro is a portable stereo-vision system that utilizes interdisciplinary skill sets for its hardware and software components. The 3D enclosure is mechanically designed and printed to optimize dimensions when fitting all the hardware. The custom PCB is designed and fabricated to safely provide battery power to all the hardware. When assembled, the cameras are calibrated to extract intrinsic parameters for depth perception. Finally, the software platform is pushed to the Raspberry Pi to take images for different applications of depth perception.
V. CONCLUSION
In this paper, The Do-Pro stereo vision camera has been physically assembled and functions similarly to commercial digital cameras. The Do-Pro accurately computes depth and demonstrates the capability to be applied to real-world problems. The low-cost and soft learning curve of the Do-Pro makes it a promising innovation for accessible computer vision technologies.

ACKNOWLEDGEMENT
The Do-Pro team would like to thank all of its team members (Timothy, Daniel, Zaya, and Harrison) for dedicating their time to completing the project. The authors would also like to thank our advisor Dr. Glenn Healey, Dr. Stuart Kleinfelder, the teaching assistants, and students of EECS159B for providing feedback and guidance to improve the quality of the project. The Do-Pro project’s funding was generously provided by Dr. Kleinfelder. We personally thank Timothy and Zaya for providing the facility of their 3D printers to print the enclosure.

REFERENCES

[1] A. Islam, M. Asikuzzaman, M. O. Khyam, M. Noor-A-Rahim, and
M. R. Pickering, “Stereo vision-based 3d positioning and tracking,” IEEE Access, vol. 8, pp. 138 771–138 787, 2020.
[2] F. Wong, R. Nagarajan, and S. Yaacob, “Application of stereovision in a navigation aid for blind people,” in Fourth International Conference on Information, Communications and Signal Processing, 2003 and the Fourth Pacific Rim Conference on Multimedia. Proceedings of the 2003 Joint, vol. 2, 2003, pp. 734–737 vol.2.
[3] M. H. Achmad, W. S. Findari, N. Q. Ann, D. Pebrianti, and M. R. Daud, “Stereo camera — based 3d object reconstruction utilizing semi-global matching algorithm,” in 2016 2nd International Conference on Science and Technology-Computer (ICST), 2016, pp. 194–199.
[4] B. Horn, B. Klaus, and P. Horn, Robot vision. MIT press, 1986.
[5] D. Scharstein, R. Szeliski, and R. Zabih, “A taxonomy and evaluation of dense two-frame stereo correspondence algorithms,” in Proceedings IEEE Workshop on Stereo and Multi-Baseline Vision (SMBV 2001) ,
2001, pp. 131–140.
[6] R. Szeliski, R. Zabih, D. Scharstein, O. Veksler, V. Kolmogorov,
A. Agarwala, M. Tappen, and C. Rother, “A comparative study of energy minimization methods for markov random fields with smoothnessbased priors,” IEEE Transactions on Pattern Analysis and Machine Intelligence, vol. 30, no. 6, pp. 1068–1080, 2008.
[7] T. Do, D. Jilani, Z. Lazar, and H. Nguyen, “”the do-pro”,” 2023. [Online]. Available: https://github.com/dotimothy/TheDoPro
[8] K.-H. Chen, Design of Switching Power Regulators, 2016, pp. 122–169.
[9] MathWorks, “Stereo camera calibrator.” [Online]. Available: https: //www.mathworks.com/help/vision/ref/stereocameracalibrator-app.html
[10] Q. Chang and T. Maruyama, “Real-time stereo vision system: A multiblock matching on gpu,” IEEE Access, vol. 6, pp. 42 030–42 046, 2018.
[11] R. Mahieu and L. Michael, “Real-time semi-global matching using cuda implementation,” 2016. [Online]. Available: https://web.stanford.edu/class/cs231a/prev projects 2016/semi global cs231.pdf (https://web.stanford.edu/class/cs231a/prev_projects_2016/semi_global_cs231.pdf)
[12] H. Edelsbrunner, D. Kirkpatrick, and R. Seidel, “On the shape of a set of points in the plane,” IEEE Transactions on Information Theory, vol. 29, no. 4, pp. 551–559, 1983.

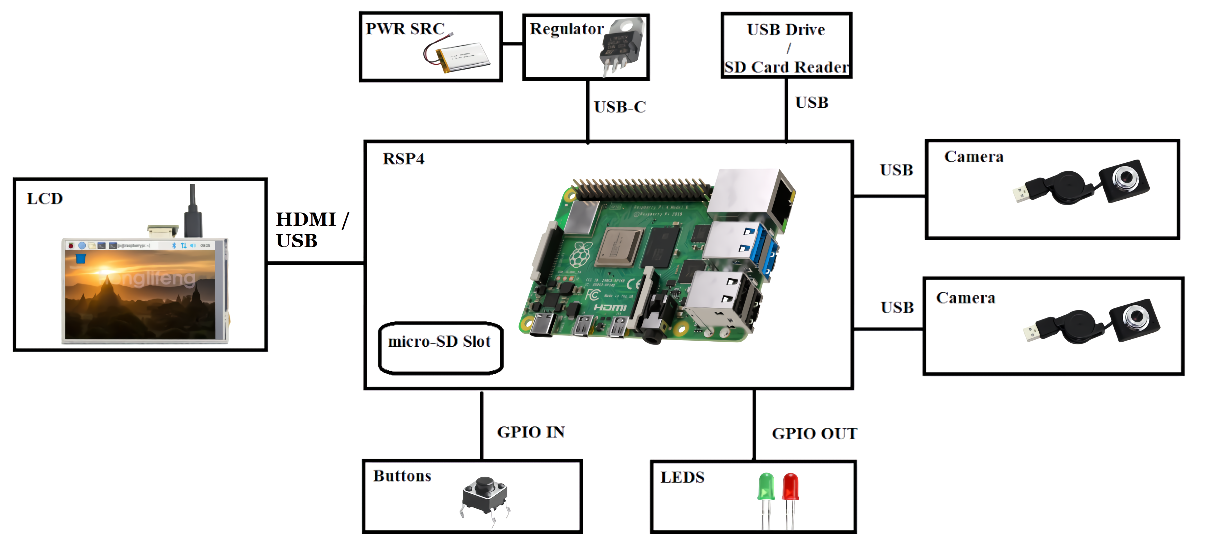
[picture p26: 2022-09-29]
Images/Hardware Connection Schematic AI Enhanced.png

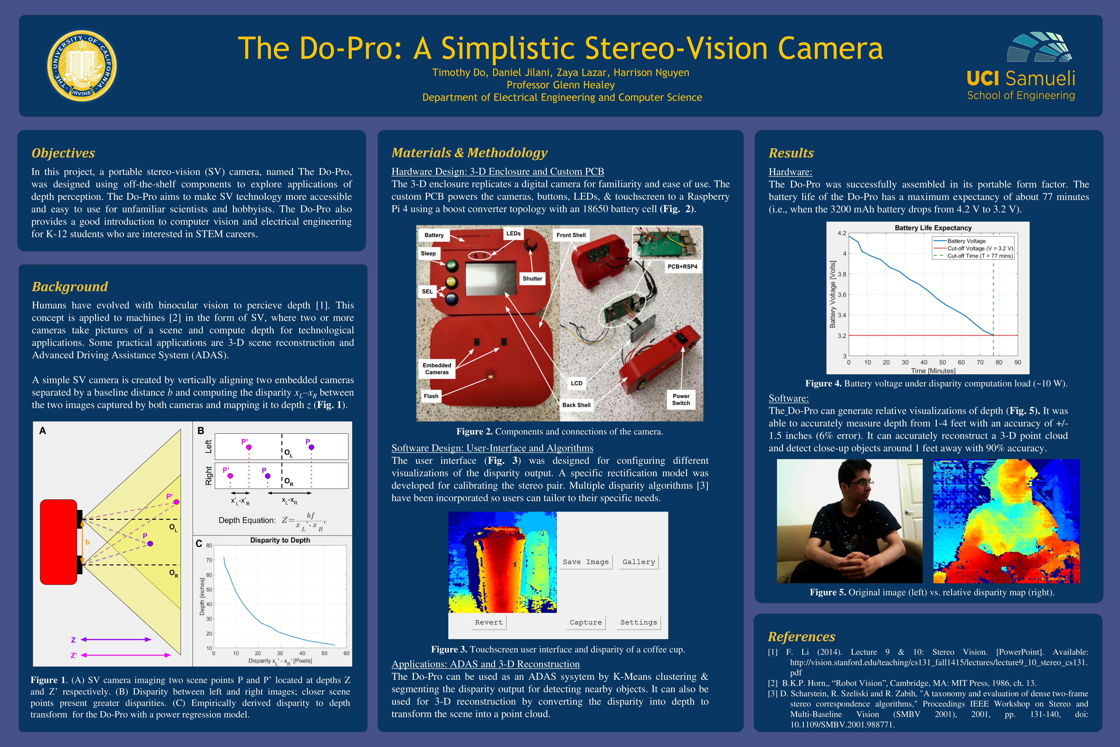
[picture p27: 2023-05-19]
Documentation/PictureThis_Poster_Final.jpg

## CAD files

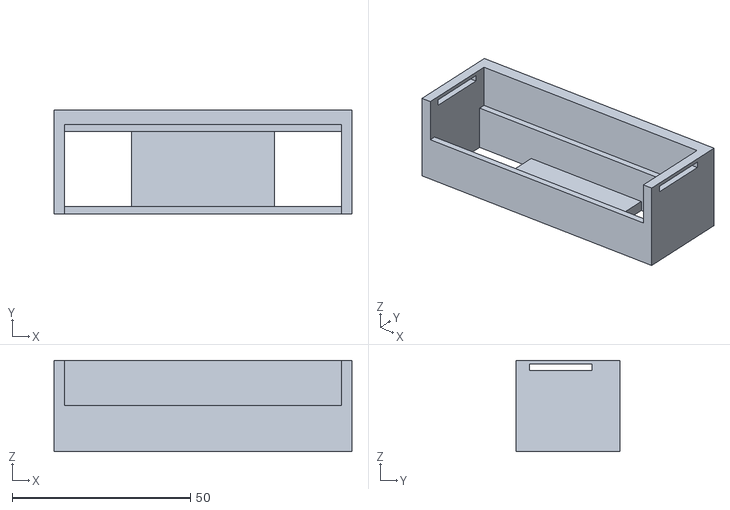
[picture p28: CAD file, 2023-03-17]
CAD/Battery_Holder_V1.stl
83.5 x 29.0 x 25.6

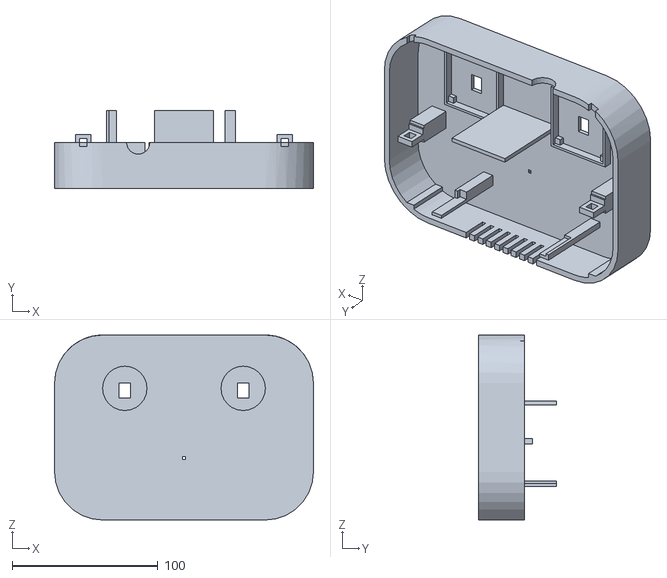
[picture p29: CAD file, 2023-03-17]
CAD/Final Models (Tentative)/Camera_Front_Plate_V4.stl
177.8 x 53.8 x 127.0

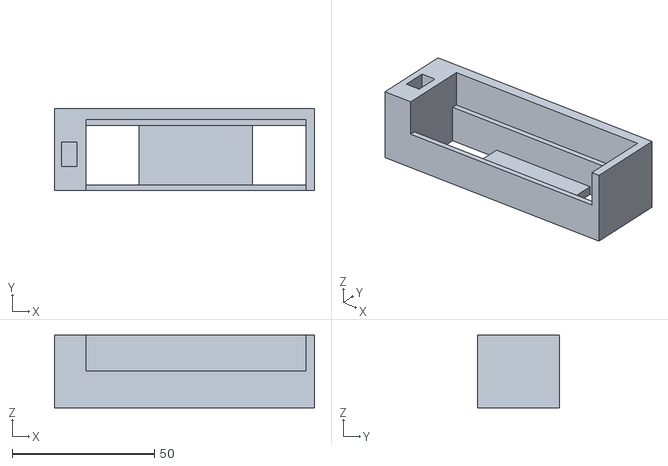
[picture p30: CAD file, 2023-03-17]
CAD/Winter Quarter/Battery_Holder.stl
91.5 x 29.0 x 25.6

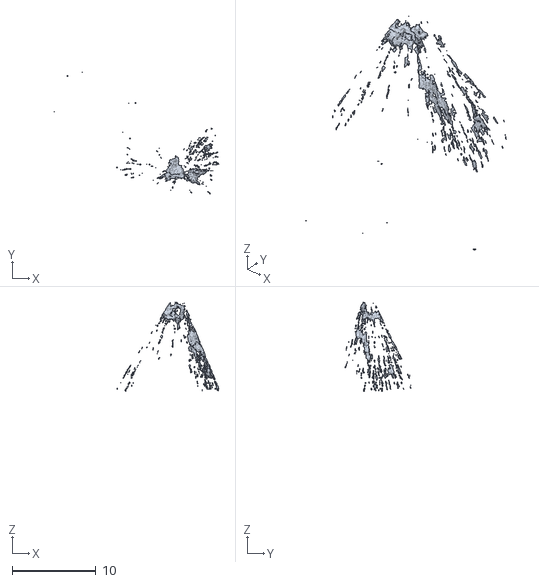
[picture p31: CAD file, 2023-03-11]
Vision/cup.stl
19.7 x 14.5 x 26.7

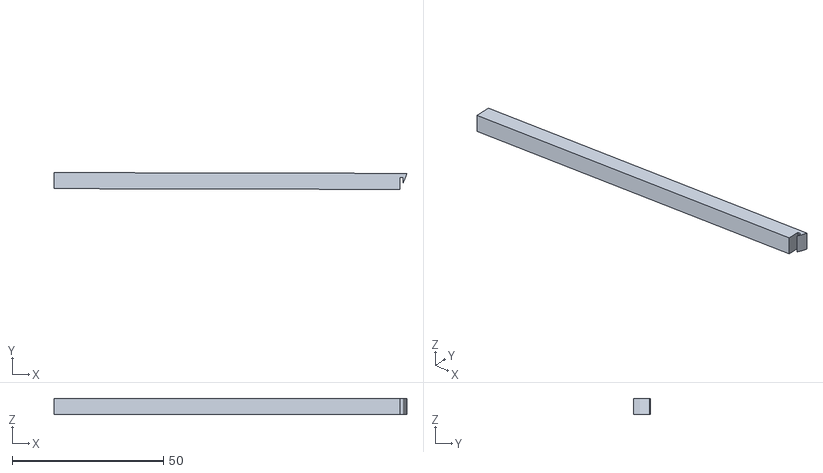
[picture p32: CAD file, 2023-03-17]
CAD/Camera_Key_Lock_Print2.stl
116.7 x 5.58 x 5.32

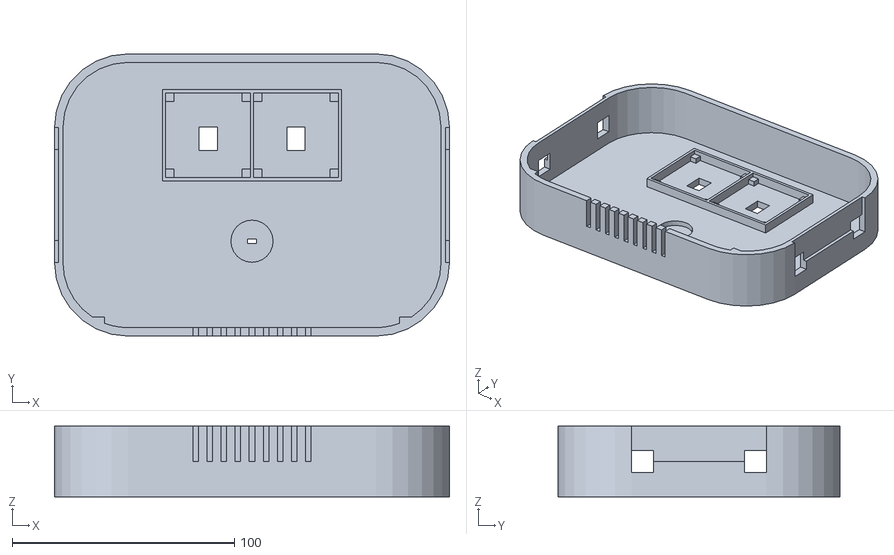
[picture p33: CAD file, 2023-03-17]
CAD/Winter Quarter/Front_Plate.stl
177.8 x 127.0 x 31.8

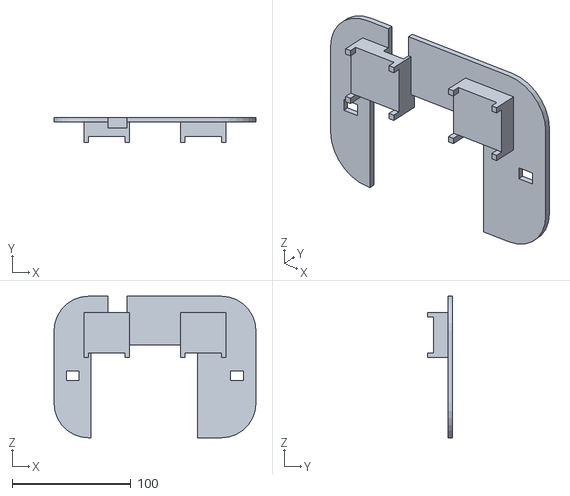
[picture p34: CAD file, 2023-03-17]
CAD/Final Models (Tentative)/Camera_Mid_Plate_V4.stl
170.2 x 21.0 x 119.4

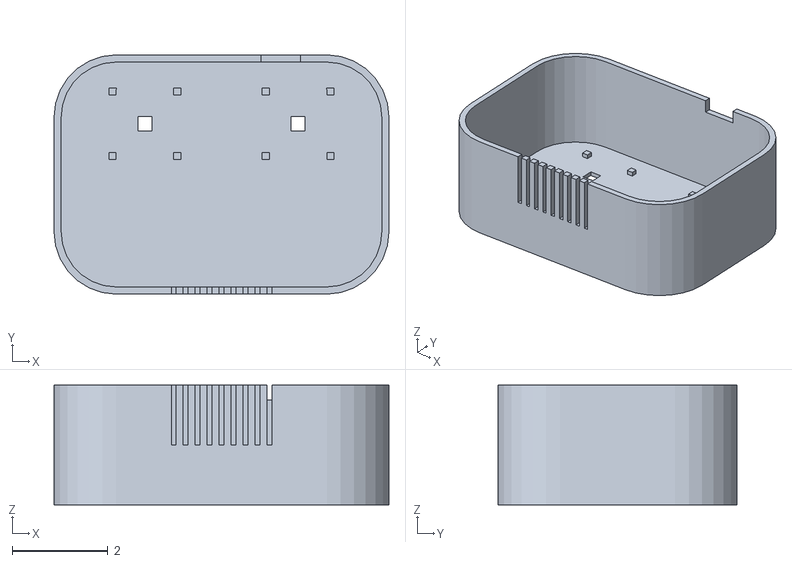
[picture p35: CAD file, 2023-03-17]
CAD/SDP_Camera_Front_Shell.stl
7.00 x 5.00 x 2.50

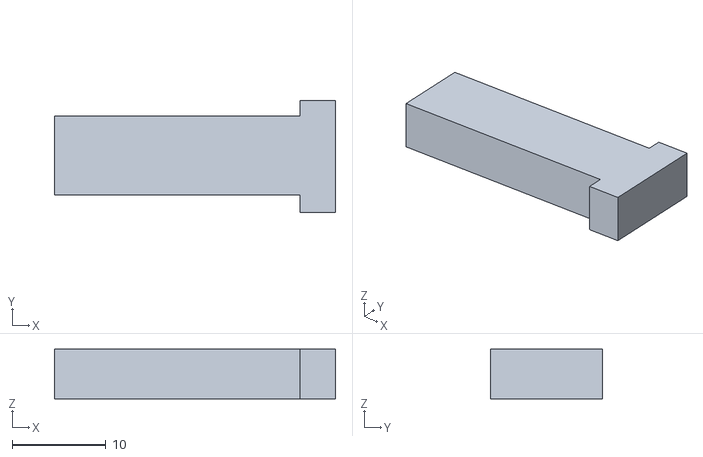
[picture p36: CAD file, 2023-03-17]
CAD/Winter Quarter/Battery_Lock.stl
30.0 x 11.9 x 5.30

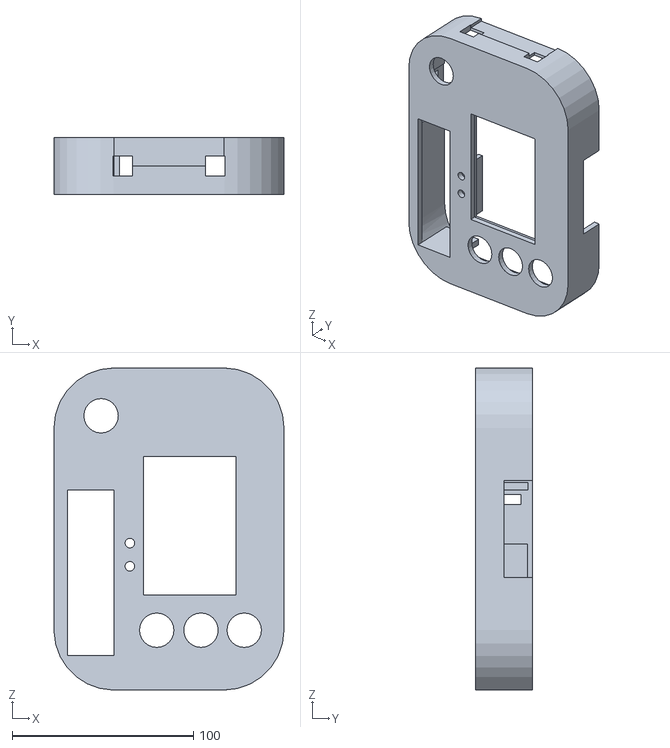
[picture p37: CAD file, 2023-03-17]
CAD/Winter Quarter/Back_Plate.stl
127.0 x 31.8 x 177.8

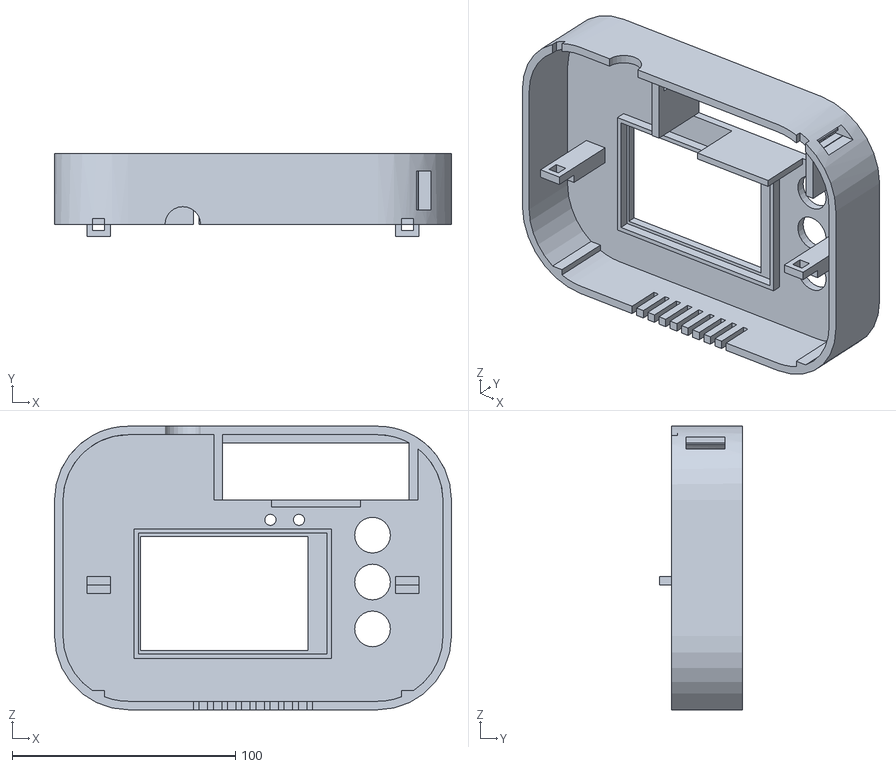
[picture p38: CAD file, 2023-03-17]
CAD/Final Models (Tentative)/Camera_Back_Plate_V4.stl
177.8 x 37.1 x 127.0

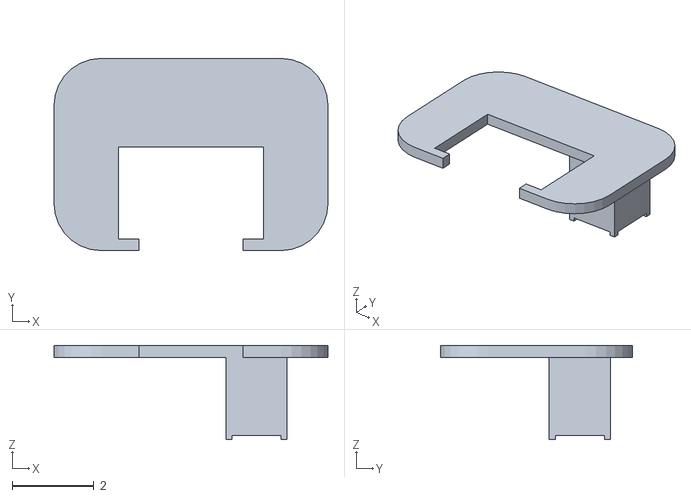
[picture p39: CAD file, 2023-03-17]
CAD/SDP_Camera_Mid_Plate.stl
6.70 x 4.70 x 2.30

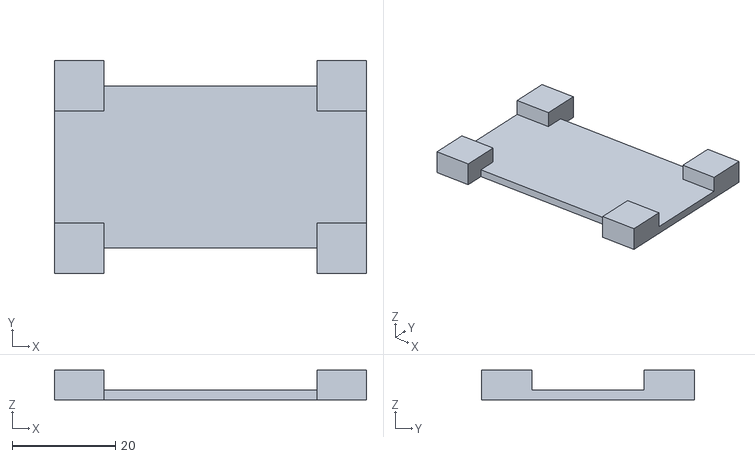
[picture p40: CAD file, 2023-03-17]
CAD/Winter Quarter/Shell_Lock_Print_Two.stl
60.6 x 41.3 x 5.81

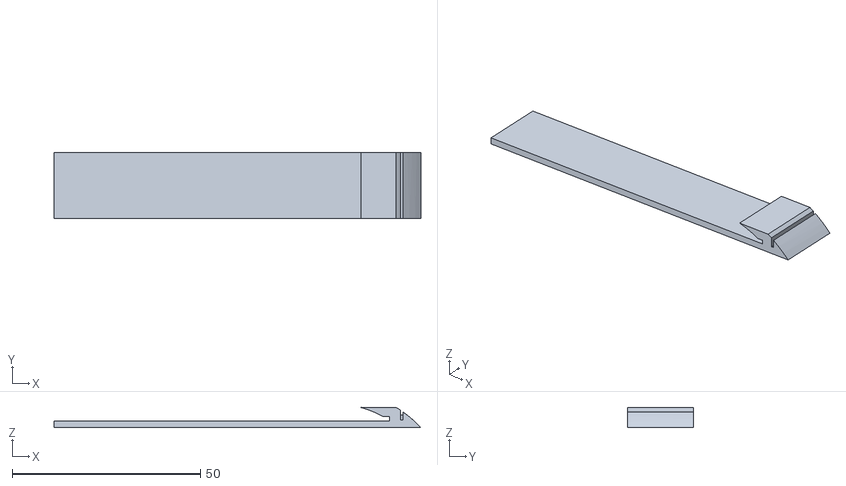
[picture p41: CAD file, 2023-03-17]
CAD/Final Models (Tentative)/Battery_Holder_Lock.stl
97.4 x 17.6 x 5.35

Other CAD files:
CAD/SDP_Camera_Back_Shell.stl
CAD/Camera_Test.stl
CAD/SDP_Camera Body_V3.dwg
CAD/Winter Quarter/Mid_Plate.stl

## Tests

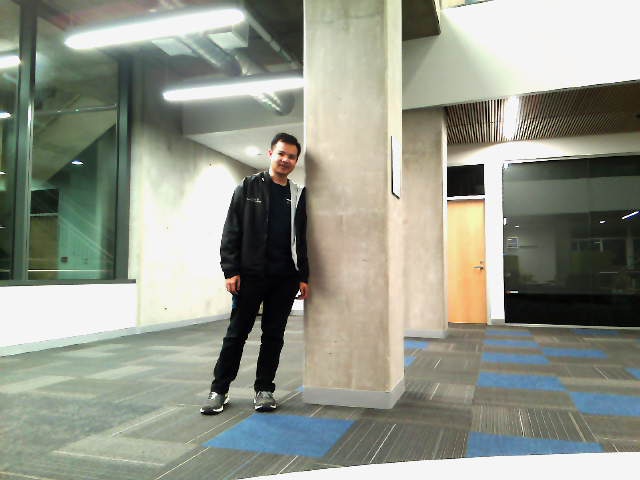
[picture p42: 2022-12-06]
Images/testscene.jpg

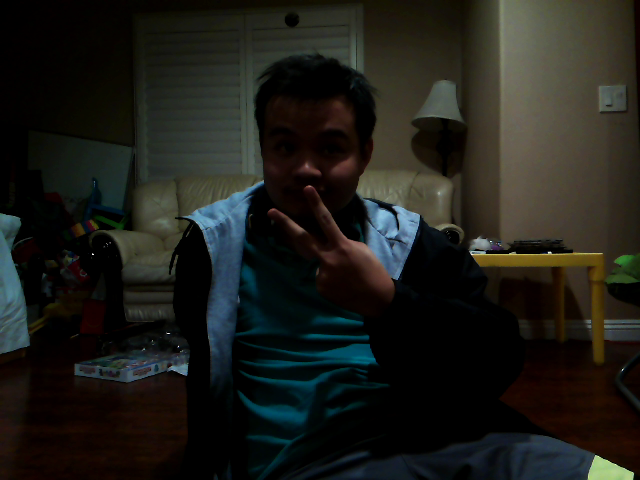
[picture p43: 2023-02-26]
Calibration/TestScenes/right/imageR7.png

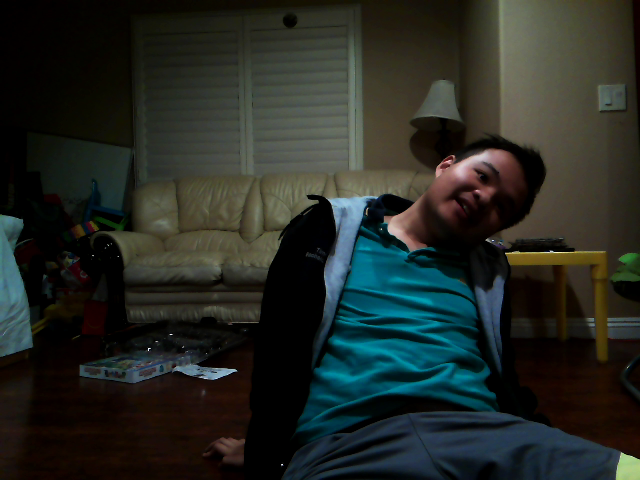
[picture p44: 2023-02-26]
Calibration/TestScenes/left/imageL9.png

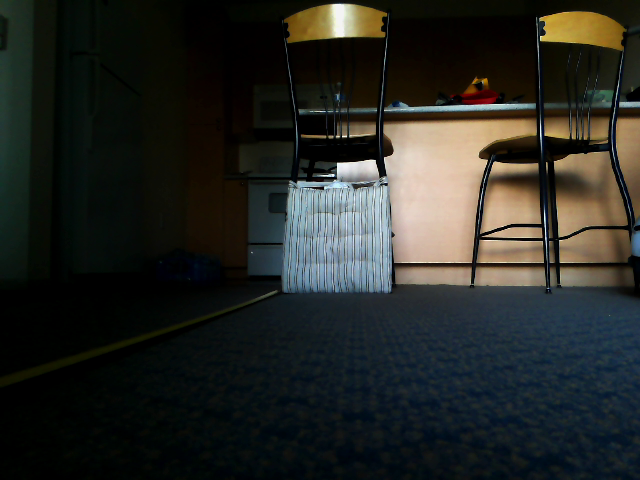
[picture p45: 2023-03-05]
Calibration/right/R_6.png

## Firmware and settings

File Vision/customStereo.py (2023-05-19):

# customStereo.py: Disparity Algorithms and The Do-Pro Configuration
# Authors: Timothy Do, Daniel Jilani, Zaya Lazar, Harrison Nguyen

# Libraries
import PIL
import matplotlib.pyplot as plt
from matplotlib.pylab import cm
import cv2 as cv
import time
import numpy as np
from scipy import ndimage as nd
from multiprocessing import Process, Queue
from os import cpu_count
import subprocess
import sys
from math import *
# if(sys.platform == 'linux'):
#     import v4l2capture

# Run Code Below If Imported

# Deprecated CUDA Support 
# haveGPU = False
# try:
#     import cupy as cp
#     haveGPU = True
# except:
#     print(f'No GPU Avaliable for cupy')

# Tries and Open the Cameras #
if(sys.platform == 'win32'):
    leftCam = cv.VideoCapture(1,cv.CAP_DSHOW)
    rightCam = cv.VideoCapture(0,cv.CAP_DSHOW)
else:
    leftCam = cv.VideoCapture('/dev/video2')
    rightCam = cv.VideoCapture('/dev/video0')


# Disparity Computation Functions
def vec_cost_block_matching(image_L_gray, image_R_gray, block_x, block_y, disp):

    # Image Dimension Specifications
    column_offset = np.floor(block_x/2).astype(int)
    row_offset = np.floor(block_y/2).astype(int)

    col_bound_L = column_offset + disp
    col_bound_U = image_L_gray.shape[1] - column_offset
    row_bound_L = row_offset
    row_bound_U = image_L_gray.shape[0] - row_offset
    rsize = image_L_gray.shape[1]

    # Define Vectorization Cost Function
    cost_vec = np.empty((row_bound_U-row_bound_L, col_bound_U-col_bound_L, disp))

    # Average Image
    L_avg = nd.uniform_filter(image_L_gray, (block_y, block_x), mode='constant')
    R_avg = nd.uniform_filter(image_R_gray, (block_y, block_x), mode='constant')

    # Define indicies
    idx = (np.arange(row_bound_L, row_bound_U)*rsize + \
            np.arange(col_bound_L, col_bound_U).reshape(-1, 1)).transpose()
    bead = (np.arange(-row_offset, row_offset+1)*rsize + \
            np.arange(-column_offset, column_offset+1).reshape(-1, 1)).reshape(-1, 1)

    # Perform cost caluclation on left image
    L_string = idx.flatten()
    L_braid  = L_string + bead
    L_cost_str = (image_L_gray).flatten()[L_braid.flatten()].reshape(L_braid.shape)
    L_avg_str = L_avg.flatten()[L_string.flatten()]
    L_residual = (L_cost_str - L_avg_str)
    L2_cost = (L_residual**2).sum(axis=0).reshape(idx.shape)

    # Perform cost caluclation on right image
    for d in range(0, disp):

      R_string = (idx - d).flatten()
      R_braid  = L_string + bead
      R_cost_str = (image_R_gray).flatten()[R_braid.flatten()].reshape(R_braid.shape)
      R_avg_str = R_avg.flatten()[R_string.flatten()]
      R_residual = (R_cost_str - R_avg_str)
      R2_cost = (R_residual**2).sum(axis=0).reshape(idx.shape)

      LR_cost_str = L_residual*R_residual
      LR_cost = LR_cost_str.sum(axis=0).reshape(idx.shape)
      
      cost_vec[:, :, d] = LR_cost/(np.sqrt(L2_cost*R2_cost)+1e-3)

    return cost_vec, row_bound_U-row_bound_L, col_bound_U-col_bound_L

def multiblock(image_L_gray, image_R_gray, block1_x, block1_y, block2_x, block2_y, block3_x, block3_y, disp):

    triblock = np.zeros(np.append(image_L_gray.shape, 3))

    block1, row_size_1, col_size_1 = vec_cost_block_matching(image_L_gray, image_R_gray, block1_x, block1_y, disp)
    block2, row_size_2, col_size_2 = vec_cost_block_matching(image_L_gray, image_R_gray, block2_x, block2_y, disp)
    block3, row_size_3, col_size_3 = vec_cost_block_matching(image_L_gray, image_R_gray, block3_x, block3_y, disp)

    R1 = (image_L_gray.shape[0] - row_size_1 - np.floor(block1_y/2))
    R2 = (image_L_gray.shape[0] - row_size_2 - np.floor(block2_y/2))
    R3 = (image_L_gray.shape[0] - row_size_3 - np.floor(block3_y/2))
    R1 = int(R1)
    R2 = int(R2)
    R3 = int(R3)

    C1 = (image_L_gray.shape[1] - col_size_1 - np.floor(block1_x/2) - 8)
    C2 = (image_L_gray.shape[1] - col_size_2 - np.floor(block2_x/2) - 8)
    C3 = (image_L_gray.shape[1] - col_size_3 - np.floor(block3_x/2) - 8)
    C1 = int(C1)
    C2 = int(C2)
    C3 = int(C3)

    triblock[R1:-R1, C1:-C1, 0] = block1[:, :, 0]
    triblock[R2:-R2, C2:-C2, 1] = block2[:, :, 0]
    triblock[R3:-R3, C3:-C3, 2] = block3[:, :, 0]

    triblock = np.prod(triblock, 2)

    return triblock

def costco_r_us(queue, disp_idx, num_disp, procs,image_R_gray,row_bound_U,row_bound_L,col_bound_U,col_bound_L,idx,L_string,bead,R_avg,L_residual,L2_cost):

    # Disp to run
    disps = range(disp_idx, num_disp, procs)

    # Define Vectorization Cost Function
    cost_vec = np.empty((row_bound_U-row_bound_L, col_bound_U-col_bound_L, len(disps)))

    # Computing disparity at specified index
    R_string = (idx - disp_idx).flatten()
    R_braid  = L_string + bead
    R_cost_str = (image_R_gray).flatten()[R_braid.flatten()].reshape(R_braid.shape)
    R_avg_str = R_avg.flatten()[R_string.flatten()]
    R_residual = (R_cost_str - R_avg_str)
    R2_cost = (R_residual**2).sum(axis=0).reshape(idx.shape)
    LR_cost_str = L_residual*R_residual
    LR_cost = LR_cost_str.sum(axis=0).reshape(idx.shape)
    cost_vec = LR_cost/np.sqrt(L2_cost*R2_cost)

    #Return calculated disparity to queue
    return queue.put(cost_vec)

def mp_cost_block(image_L_gray, image_R_gray, block_x, block_y, disp, procs):

    # Define Multiprocessing
    q = Queue()
    disp_map = []
    processes = []

    # Image Dimension Specifications
    column_offset = np.floor(block_x/2).astype(int)
    row_offset = np.floor(block_y/2).astype(int)

    col_bound_L = column_offset + disp
    col_bound_U = image_L_gray.shape[1] - column_offset
    row_bound_L = row_offset
    row_bound_U = image_L_gray.shape[0] - row_offset
    rsize = image_L_gray.shape[1]

    # Define Vectorization Cost Function
    cost_vec = np.empty((row_bound_U-row_bound_L, col_bound_U-col_bound_L, procs))

    # Average Image
    L_avg = nd.uniform_filter(image_L_gray, (block_y, block_x), mode='constant')
    R_avg = nd.uniform_filter(image_R_gray, (block_y, block_x), mode='constant')

    # Define indicies
    idx = (np.arange(row_bound_L, row_bound_U)*rsize + \
            np.arange(col_bound_L, col_bound_U).reshape(-1, 1)).transpose()
    bead = (np.arange(-row_offset, row_offset+1)*rsize + \
            np.arange(-column_offset, column_offset+1).reshape(-1, 1)).reshape(-1, 1)

    # Perform cost caluclation on left image
    L_string = idx.flatten()
    L_braid  = L_string + bead
    L_cost_str = (image_L_gray).flatten()[L_braid.flatten()].reshape(L_braid.shape)
    L_avg_str = L_avg.flatten()[L_string.flatten()]
    L_residual = (L_cost_str - L_avg_str)
    L2_cost = (L_residual**2).sum(axis=0).reshape(idx.shape)

    for i in range(0, procs):
        p = Process(target=costco_r_us, args = [q, i, disp, procs,image_R_gray,row_bound_U,row_bound_L,col_bound_U,col_bound_L,idx,L_string,bead,R_avg,L_residual,L2_cost])
        p.start()
        processes.append(p)

    i = 0
    for p in processes:
        cost_vec[:, :, i] = q.get()
        i = i + 1

    for p in processes:
        p.join()

    cost = np.max(cost_vec, axis=2)

    return cost

def vec_cost_block_matching_gpu(image_L_gray, image_R_gray, block_x, block_y, disp):

    # Image Dimension Specifications
    column_offset = cp.floor(block_x/2).astype(int)
    row_offset = cp.floor(block_y/2).astype(int)

    col_bound_L = column_offset + disp
    col_bound_U = image_L_gray.shape[1] - column_offset
    row_bound_L = row_offset
    row_bound_U = image_L_gray.shape[0] - row_offset
    rsize = image_L_gray.shape[1]

    # Define Vectorization Cost Function
    cost_vec = cp.empty((row_bound_U-row_bound_L, col_bound_U-col_bound_L, disp))

    # Average Image
    L_avg = nd.uniform_filter(image_L_gray, (block_y, block_x), mode='constant')
    R_avg = nd.uniform_filter(image_R_gray, (block_y, block_x), mode='constant')

    # Define indicies
    idx = (cp.arange(row_bound_L, row_bound_U)*rsize + \
            cp.arange(col_bound_L, col_bound_U).reshape(-1, 1)).transpose()
    bead = (cp.arange(-row_offset, row_offset+1)*rsize + \
            cp.arange(-column_offset, column_offset+1).reshape(-1, 1)).reshape(-1, 1)

    # Perform cost caluclation on left image
    L_string = idx.flatten()
    L_braid  = L_string + bead
    L_cost_str = (image_L_gray).flatten()[L_braid.flatten()].reshape(L_braid.shape)
    L_avg_str = L_avg.flatten()[L_string.flatten()]
    L_residual = (L_cost_str - L_avg_str)
    L2_cost = (L_residual**2).sum(axis=0).reshape(idx.shape)

    # Perform cost caluclation on right image
    for d in range(0, disp):

      R_string = (idx - d).flatten()
      R_braid  = L_string + bead
      R_cost_str = (image_R_gray).flatten()[R_braid.flatten()].reshape(R_braid.shape)
      R_avg_str = R_avg.flatten()[R_string.flatten()]
      R_residual = (R_cost_str - R_avg_str)
      R2_cost = (R_residual**2).sum(axis=0).reshape(idx.shape)

      LR_cost_str = L_residual*R_residual
      LR_cost = LR_cost_str.sum(axis=0).reshape(idx.shape)
      cost_vec[:, :, d] = LR_cost/cp.sqrt(L2_cost*R2_cost)

    return cost_vec, row_bound_U-row_bound_L, col_bound_U-col_bound_L

def multiblock_gpu(image_L_gray, image_R_gray, block1_x, block1_y, block2_x, block2_y, block3_x, block3_y, disp):

    triblock = cp.zeros(cp.append(image_L_gray.shape, 3))

    block1, row_size_1, col_size_1 = vec_cost_block_matching(image_L_gray, image_R_gray, block1_x, block1_y, disp)
    block2, row_size_2, col_size_2 = vec_cost_block_matching(image_L_gray, image_R_gray, block2_x, block2_y, disp)
    block3, row_size_3, col_size_3 = vec_cost_block_matching(image_L_gray, image_R_gray, block3_x, block3_y, disp)

    R1 = (image_L_gray.shape[0] - row_size_1 - cp.floor(block1_y/2))
    R2 = (image_L_gray.shape[0] - row_size_2 - cp.floor(block2_y/2))
    R3 = (image_L_gray.shape[0] - row_size_3 - cp.floor(block3_y/2))
    R1 = int(R1)
    R2 = int(R2)
    R3 = int(R3)

    C1 = (image_L_gray.shape[1] - col_size_1 - cp.floor(block1_x/2) - 8)
    C2 = (image_L_gray.shape[1] - col_size_2 - cp.floor(block2_x/2) - 8)
    C3 = (image_L_gray.shape[1] - col_size_3 - cp.floor(block3_x/2) - 8)
    C1 = int(C1)
    C2 = int(C2)
    C3 = int(C3)

    triblock[R1:-R1, C1:-C1, 0] = block1[:, :, 0]
    triblock[R2:-R2, C2:-C2, 1] = block2[:, :, 0]
    triblock[R3:-R3, C3:-C3, 2] = block3[:, :, 0]

    triblock = cp.prod(triblock, 2)

    return triblock

def vec_NCC(image_L_gray, image_R_gray, block_x, block_y, disp):

    image_L_gray = image_L_gray + 1e-9
    image_R_gray = image_R_gray + 1e-9

    # Image Dimension Specifications
    column_offset = np.floor(block_x/2).astype(int)
    row_offset = np.floor(block_y/2).astype(int)

    col_bound_L = column_offset + disp
    col_bound_U = image_L_gray.shape[1] - column_offset
    row_bound_L = row_offset
    row_bound_U = image_L_gray.shape[0] - row_offset
    rsize = image_L_gray.shape[1]

    # Define Vectorization Cost Function
    ncc = np.empty((row_bound_U-row_bound_L, col_bound_U-col_bound_L, disp))

    # Average Image
    L_avg = nd.uniform_filter(image_L_gray, (block_y, block_x), mode='constant')
    R_avg = nd.uniform_filter(image_R_gray, (block_y, block_x), mode='constant')

    # Define indicies
    idx = (np.arange(row_bound_L, row_bound_U)*rsize + \
            np.arange(col_bound_L, col_bound_U).reshape(-1, 1)).transpose()
    bead = (np.arange(-row_offset, row_offset+1)*rsize + \
            np.arange(-column_offset, column_offset+1).reshape(-1, 1)).reshape(-1, 1)

    # Perform cost caluclation on left image
    L_string = idx.flatten()
    L_braid  = L_string + bead
    L_cost_str = (image_L_gray).flatten()[L_braid.flatten()].reshape(L_braid.shape)
    L_avg_str = L_avg.flatten()[L_string.flatten()]
    L_residual = (L_cost_str - L_avg_str)
    L2_cost = (L_residual**2).sum(axis=0).reshape(idx.shape)

    # Perform cost caluclation on right image
    for d in range(0, disp):

      R_string = (idx - d).flatten()
      R_braid  = L_string + bead
      R_cost_str = (image_R_gray).flatten()[R_braid.flatten()].reshape(R_braid.shape)
      R_avg_str = R_avg.flatten()[R_string.flatten()]
      R_residual = (R_cost_str - R_avg_str)
      R2_cost = (R_residual**2).sum(axis=0).reshape(idx.shape)

      LR_cost_str = L_residual*R_residual
      LR_cost = LR_cost_str.sum(axis=0).reshape(idx.shape)
      
      ncc[:, :, d] = LR_cost/(np.sqrt(L2_cost*R2_cost)+1e-2)

    #cost_vec = nd.uniform_filter(cost_vec, (block_y, block_x, 1), mode='constant') * block_x * block_y
    #cost_vec = np.max(cost_vec, axis=2)

    ncc = np.max(nd.uniform_filter(ncc, (17, 17, 1), mode='constant'), 2)

    return ncc

def rawDispToPix(raw):
    return raw.astype(np.float32)/16

def disparityToDepthScanning(disparity):
    depth = 613.33*np.power(disparity.clip(min=0.00001),-1.001)
    depth[depth == 613.33*np.power(0.00001,-1.001)] = 0
    return depth 

def disparityToDepthADAS(disparity):
    depth = 264.2*np.power(disparity.clip(min=0.00001),-0.789)
    depth[depth == 264.2*np.power(0.00001,-0.789)] = 0
    return depth

# Camera Configurations

def checkCams():
    global leftCam
    global rightCam 
    return leftCam.isOpened() and rightCam.isOpened()

def adjustExposure(exposure):
    global leftCam
    global rightCam
    if(sys.platform == 'win32'):
        leftCam.set(cv.CAP_PROP_EXPOSURE,exposure)
        rightCam.set(cv.CAP_PROP_EXPOSURE,exposure)
    else:
        leftCam.release()
        rightCam.release()
        percent = int(150+(exposure*10))
        if(exposure < -10):
            percent = 0
        subprocess.check_call(f"v4l2-ctl -d /dev/video0 -c exposure_absolute={str(percent)}",shell=True)
        subprocess.check_call(f"v4l2-ctl -d /dev/video2 -c exposure_absolute={str(percent)}",shell=True)
        leftCam = cv.VideoCapture('/dev/video2')
        rightCam = cv.VideoCapture('/dev/video0')
# OpenCV Stereo Objecats
stereoBM = cv.StereoBM_create(numDisparities=256,blockSize=17)
stereoSGBM = cv.StereoSGBM_create(minDisparity=0, numDisparities=256, blockSize=3, P1=8*3*3, P2=32*3*3, disp12MaxDiff=10, uniquenessRatio=10, speckleWindowSize=150, speckleRange=32)

def adjustNumDisp(num):
    global stereoBM
    global stereoSGBM
    stereoBM = cv.StereoBM_create(numDisparities=num,blockSize=9)
    stereoSGBM = cv.StereoSGBM_create(minDisparity=0, numDisparities=num, blockSize=7, P1=8*7*7, P2=32*7*7, disp12MaxDiff=10, uniquenessRatio=10, speckleWindowSize=150, speckleRange=32)

def correctPosition():
    global leftCam
    global rightCam
    temp = leftCam
    leftCam = rightCam
    rightCam = temp

#OpenCV StereoMap for Rectification
cv_file = cv.FileStorage()
cv_file.open('../Calibration/stereoMap_matlab.xml', cv.FileStorage_READ)

stereoMapL_x = cv_file.getNode('stereoMapL_x').mat()
stereoMapL_y = cv_file.getNode('stereoMapL_y').mat()
stereoMapR_x = cv_file.getNode('stereoMapR_x').mat()
stereoMapR_y = cv_file.getNode('stereoMapR_y').mat()

# Parameters for the Simulation
counter = 0
# depths = [72,66,60,54,48,45,42,39,36,33,30,27,24,21,18,15,12,9,6,3]
depths = [12,18,24,30,36]
interval = 5
def readLeft(mode):
    if(mode == 0): #Dev, Will Be an Image
        global counter
        counter = counter + 1
        return cv.cvtColor(cv.imread(f'../Images/Pillow/L_{str(depths[trunc((counter % (interval*len(depths)))/(interval))])}.jpg',1),cv.COLOR_BGR2RGB)
    elif(mode == 1): #Webcam
        return np.uint8(1.25*cv.cvtColor(leftCam.read()[1],cv.COLOR_BGR2RGB))
    elif(mode == 2): #Cup
        return cv.cvtColor(cv.imread(f'../Images/cup_L.jpg',1),cv.COLOR_BGR2RGB)
    elif(mode == 3): #Daniel
        return cv.cvtColor(cv.imread(f'../Images/daniel2_L.jpg',1),cv.COLOR_BGR2RGB)
    elif(mode == 4): #Tim
        return cv.cvtColor(cv.imread(f'../Images/tim_L.png',1),cv.COLOR_BGR2RGB)

def readRight(mode):
    if(mode == 0): #Dev, Will Be an Image
        global counter
        counter = counter + 1
        return cv.cvtColor(cv.imread(f'../Images/Pillow/R_{str(depths[trunc((counter % (interval*len(depths)))/(interval))])}.jpg',1),cv.COLOR_BGR2RGB)
    elif(mode == 1): #Webcam
        return np.uint8(1.25*cv.cvtColor(rightCam.read()[1],cv.COLOR_BGR2RGB))
    elif(mode == 2): #Cup
        return cv.cvtColor(cv.imread(f'../Images/cup_R.jpg',1),cv.COLOR_BGR2RGB)
    elif(mode == 3): #Daniel
        return cv.cvtColor(cv.imread(f'../Images/daniel2_R.jpg',1),cv.COLOR_BGR2RGB)
    elif(mode == 4): #Tim
        return cv.cvtColor(cv.imread(f'../Images/tim_R.png',1),cv.COLOR_BGR2RGB)


def rectifyLeft(leftFrame):
    return cv.remap(leftFrame,stereoMapL_x,stereoMapL_y,cv.INTER_LANCZOS4, cv.BORDER_CONSTANT, 0)

def rectifyRight(rightFrame):
    return cv.remap(rightFrame,stereoMapR_x,stereoMapR_y,cv.INTER_LANCZOS4, cv.BORDER_CONSTANT, 0)

def processCapture(leftFrame,rightFrame,algor,downscale,relative,cmap):
    # leftFrameGray = cv.equalizeHist(cv.cvtColor(leftFrame, cv.COLOR_BGR2GRAY))
    # rightFrameGray = cv.equalizeHist(cv.cvtColor(rightFrame, cv.COLOR_BGR2GRAY))
    #clahe = cv.createCLAHE(clipLimit=2.0, tileGridSize=(8,8))
    # leftFrameGray = clahe.apply(cv.cvtColor(leftFrame, cv.COLOR_BGR2GRAY))
    # rightFrameGray = clahe.apply(cv.cvtColor(rightFrame, cv.COLOR_BGR2GRAY))
    if(len(leftFrame.shape) > 2 or len(rightFrame.shape) > 2):
        leftFrameGray = cv.cvtColor(leftFrame, cv.COLOR_BGR2GRAY)
        rightFrameGray = cv.cvtColor(rightFrame, cv.COLOR_BGR2GRAY)
    else:
        leftFrameGray, rightFrameGray = leftFrame, rightFrame
    if(algor != 0 and algor != 1):
        leftFrameGray = leftFrameGray + 1e-1
        rightFrameGray = rightFrameGray + 1e-1
    if(downscale != 1):
        leftFrameGray = cv.resize(leftFrameGray,(int(leftFrameGray.shape[1]/downscale),int(leftFrameGray.shape[0]/downscale)),interpolation=cv.INTER_CUBIC)
        rightFrameGray = cv.resize(rightFrameGray,(int(rightFrameGray.shape[1]/downscale),int(rightFrameGray.shape[0]/downscale)),interpolation=cv.INTER_CUBIC)
    if(algor == 0): #OpenCV Block Matching
        disparity = stereoBM.compute(leftFrameGray,rightFrameGray)     
        cv.filterSpeckles(disparity,newVal=0,maxSpeckleSize=100,maxDiff=1)
        #disparity = ((disparity+16)/4 - 1).astype(np.uint8) #Normalize 
    elif(algor == 1): #OpenCV Semi-Global Block Matching
        disparity = stereoSGBM.compute(leftFrameGray,rightFrameGray) 
        #disparity = ((disparity+16)/4 - 1).astype(np.uint8) #Normalzie
    elif(algor == 2): #Cost Block Matching
        result = vec_cost_block_matching(leftFrameGray, rightFrameGray, 5, 5, 32)
        disparity = result[0][:,:,0]
    elif(algor == 3): #Multiblock
        disparity = multiblock(leftFrameGray, rightFrameGray, 9, 9, 5, 5, 7, 7, 16)
    elif(algor == 4): #Multiprocess Cost Block
        disparity = mp_cost_block(leftFrameGray,rightFrameGray,9, 9, 16, cpu_count())
    elif(algor == 5): #NCC Cost Block
        disparity = vec_NCC(leftFrameGray,rightFrameGray,3,3,32)
    elif(algor == 6): #Cost Block Matching GPU
        if(haveGPU):
            result = vec_cost_block_matching_gpu(leftFrameGray, rightFrameGray, 9, 9, 8)
        else:
            print(f'No GPU: Fallback to CPU Computation')
            result = vec_cost_block_matching(leftFrameGray, rightFrameGray, 9, 9, 8)
        disparity = result[0][:,:,0]
    elif(algor == 7): #Multiblock GPU
        if(haveGPU): 
            result = multiblock_gpu(leftFrameGray,rightFrameGray,9,9,21,3,3,21,16)
        else:
            print(f'No GPU: Fallback to CPU Computation')
            disparity = multiblock(leftFrameGray, rightFrameGray, 9, 9, 21, 3, 3, 21, 16)
    if(downscale != 1):
        disparity = cv.resize(disparity,(disparity.shape[1]*downscale,disparity.shape[0]*downscale),interpolation=cv.INTER_CUBIC)
    if(algor < 2):
        disparity = np.uint8(255*cv.normalize(disparity,disparity,0,1,cv.NORM_MINMAX,cv.CV_32F))
        #disparity = cv.cvtColor(cv.applyColorMap(cv.equalizeHist(np.uint8(255*disparity)),cv.COLORMAP_JET),cv.COLOR_RGB2BGR)
        #disparity = cv.cvtColor(cv.applyColorMap(clahe.apply(np.uint8(255*disparity)),cv.COLORMAP_JET),cv.COLOR_RGB2BGR)
        if(relative):
            disparity = cv.equalizeHist(disparity)
        cmaps = {
            'jet':cv.COLORMAP_JET,
            'bone':cv.COLORMAP_BONE,
            'rainbow':cv.COLORMAP_RAINBOW,
            'hsv':cv.COLORMAP_HSV,
            'viridis':cv.COLORMAP_VIRIDIS
        }
        if(cmap != 'gray'): #gray is just raw normalization
            disparity = cv.cvtColor(cv.applyColorMap(disparity,cmaps[cmap]),cv.COLOR_RGB2BGR)
    else: 
        cmaps = {
            'jet':cm.jet,
            'gray':cm.gray,
            'bone':cm.bone,
            'rainbow':cm.rainbow,
            'hsv':cm.hsv,
            'viridis':cm.viridis
        }
        disparity = cv.cvtColor(np.uint8(cmaps[cmap](disparity)*255),cv.COLOR_RGBA2BGR)
    return disparity

if(checkCams()):
    adjustExposure(0)
    leftCam.set(cv.CAP_PROP_SHARPNESS,200)
    rightCam.set(cv.CAP_PROP_SHARPNESS,200)
    leftCam.set(cv.CAP_PROP_FRAME_WIDTH, 640)
    leftCam.set(cv.CAP_PROP_FRAME_HEIGHT, 480)
    rightCam.set(cv.CAP_PROP_FRAME_WIDTH, 640)
    rightCam.set(cv.CAP_PROP_FRAME_HEIGHT,480)
    # leftCam.set(cv.CAP_PROP_AUTO_EXPOSURE,0.75)
    # rightCam.set(cv.CAP_PROP_AUTO_EXPOSURE,0.75)
else:
    leftCam.release()
    rightCam.release()
    print(f'No Webcams')
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

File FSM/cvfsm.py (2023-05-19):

from time import sleep, localtime
import os
import cv2 as cv
import tkinter as tk
import tkinter.font as tkFont
from PIL import Image, ImageTk
import sys

if(sys.platform == 'linux' or sys.platform == 'linux2'):
	import RPi.GPIO as GPIO
	sys.path.insert(1,'/home/tdlh/Github/TheDoPro/Vision')
else: 
	sys.path.insert(1,'../Vision')
programMode = 1


import customStereo as cs 
if(programMode == 1 and not(cs.checkCams())):
	programMode = 2


# GPIO Functions 

def setupGPIO(master):
	GPIO.setwarnings(False)
	GPIO.setmode(GPIO.BOARD)
	for button in master['buttons']: 
		GPIO.setup(master['buttons'][button]['pin'],GPIO.IN,pull_up_down=GPIO.PUD_UP)
	for led in master['leds']:
		GPIO.setup(master['leds'][led]['pin'],GPIO.OUT)

def updateButtonState(master): 
	for button in master['buttons']: 
		master['buttons'][button]['state'] = 0 if(GPIO.input(master['buttons'][button]['pin'])) else 1

def printButtonState(master):
	for button in master['buttons']:
		print(f"{button}: {master['buttons'][button]['state']}")
	print()


# FSM Functions


def imagePreview(root,master,lbl):
	if(master['settings']['save'] == 'On'):
		sleep(3)
	im = []
	image_L = []
	image_R = []
	if(master['lastState'] != master['settings']['state']):
		setupPreview(root,master,lbl)
	if(sys.platform == 'linux' or sys.platform == 'linux2'):
		updateButtonState(master)
		if(master['buttons']['sel1']['state'] and not(master['buttons']['sel2']['state'])and not(master['buttons']['capture']['state'])): #Toggle Right/Left
			updateState(master,'Right' if(master['settings']['state'] == 'Left') else 'Left')
		elif(not(master['buttons']['sel1']['state']) and master['buttons']['sel2']['state'] and not(master['buttons']['capture']['state'])): #Settings
			configSettings(master)
		elif(not(master['buttons']['sel1']['state']) and not(master['buttons']['sel2']['state']) and master['buttons']['capture']['state']): #Capture
			updateState(master,'Capture')
		elif(master['buttons']['sel1']['state'] and master['buttons']['sel2']['state'] and not(master['buttons']['capture']['state'])): #Gallery
			openGallery('./results')
	root.title(f'TheDoPro Visualization Mode (State: {master["settings"]["state"]})')
	if(master['settings']['state'] == 'Right'):
		im = cs.readRight(programMode)
		if(master['settings']['rectification'] == 'On'):
			im = cs.rectifyRight(im)
		if(sys.platform == 'linux' or sys.platform == 'linux2'):
			GPIO.output(master['leds']['capture']['pin'],0)
			GPIO.output(master['leds']['flash']['pin'],0)
	elif(master['settings']['state'] == 'Left'):
		im = cs.readLeft(programMode)
		if(master['settings']['rectification'] == 'On'):
			im = cs.rectifyLeft(im)
		if(sys.platform == 'linux' or sys.platform == 'linux2'):
			GPIO.output(master['leds']['capture']['pin'],0)
			GPIO.output(master['leds']['flash']['pin'],0)
	elif(master['settings']['state'] == 'Capture'):
		if(sys.platform == 'linux' or sys.platform == 'linux2'):
			GPIO.output(master['leds']['capture']['pin'],1)
			if(master['settings']['flash'] == 'On'):
				GPIO.output(master['leds']['flash']['pin'],1)
			else: 
				GPIO.output(master['leds']['flash']['pin'],0)
		root.title(f'TheDoPro Visualization Mode (State: {master["settings"]["state"]}: {master["settings"]["mode"]})')
		config = {'OpenCV_BM': {
			'algor':0,
			'downscale':1
		},
		'OpenCV_SGBM': {
			'algor':1,
			'downscale':1
		},
		'Cost Block':{
			'algor':2,
			'downscale':4
		},
		'Multiblock':{
			'algor':3,
			'downscale':8
		}}
		image_L = cs.readLeft(programMode)
		image_R = cs.readRight(programMode)
		if(master['settings']['rectification'] == 'On'):
			image_L = cs.rectifyLeft(image_L)
			image_R = cs.rectifyRight(image_R)
		re = master['settings']['relative'] == 'On' 
		im = cs.processCapture(image_L,image_R,config[master['settings']['mode']]['algor'],config[master['settings']['mode']]['downscale'],re,master['settings']['colormap'])
	if(master['settings']['save'] == 'On'):
		if(not os.path.exists('./results')):
			os.mkdir('./results')
		saveImage(im,'./results')
		if(master['settings']['state'] == 'Capture'):
			saveImage(image_L,'./results')
			saveImage(image_R,'./results')
		master['settings']['save'] = 'Off'
	im = cv.resize(im,(200,150))
	imTk = ImageTk.PhotoImage(image=Image.fromarray(im))
	lbl.imtk = imTk
	lbl.configure(image=imTk)
	master['lastState'] =  master['settings']['state']
	lbl.after(50,imagePreview,root,master,lbl)
	
def setupPreview(root,master,lbl):
	root.geometry('640x480')
	if(sys.platform == 'win32'):
		root.iconbitmap('../Images/favicon.ico')
	for widget in root.winfo_children():
		if isinstance(widget,tk.Button):
			widget.destroy()
	lbl.grid(row=1,column=1)
	if(master['settings']['state'] != 'Capture'):
		tk.Button(root,text="Change Camera",font=("Courier",12),command=lambda:changeCamera(master)).grid(row=2,column=1,padx=10,pady=10)
	else:
		tk.Button(root,text="Revert",font=("Courier",12),command=lambda:changeCamera(master)).grid(row=2,column=1,padx=10,pady=10)
	tk.Button(root,text="Save Image",font=("Courier",12),command=lambda:turnOnSave(master)).grid(row=1,column=2,padx=10,pady=10)
	tk.Button(root,text="Gallery",font=("Courier",12),command=lambda:openGallery('results')).grid(row=1,column=3,padx=10,pady=10)
	tk.Button(root,text="Capture",font=("Courier",12),command=lambda:updateState(master,'Capture')).grid(row=2,column=2,padx=10,pady=10)
	tk.Button(root,text="Settings",font=("Courier",12),command=lambda:configSettings(master)).grid(row=2,column=3,padx=10,pady=10)
	if(programMode == 1):
		tk.Button(root,text="Correct",font=("Courier",12),command=lambda:cs.correctPosition()).grid(row=3,column=3,padx=10,pady=10)

def updateState(master,state):
	master['settings']['state'] = state
	print(f"Updated Window State to {master['settings']['state']}")

def changeCamera(master):
	if(master['settings']['state'] == 'Right'):
		updateState(master,'Left')
	else: 
		master['settings']['state'] = 'Right'
		updateState(master,'Right')

def turnOnSave(master):
	master['settings']['save'] = 'On'

def openGallery(directory):
	if(not(os.path.exists('./results'))):
		os.mkdir('./results')
	if(sys.platform == 'win32'):
		os.system(f'explorer {os.getcwd()}\\results')
	elif(sys.platform == 'linux' or sys.platform == 'linux2'):
		os.system(f'pcmanfm {os.getcwd()}/results')


def saveImage(im,outputDir):
	current = localtime()
	outputPath = f'{outputDir}/{current.tm_mon}{current.tm_mday}_{current.tm_year}_{current.tm_hour}_{current.tm_min}_{current.tm_sec}.jpg'
	dup = 1
	while(os.path.exists(outputPath)):
		outputPath = f'{outputDir}/{current.tm_mon}{current.tm_mday}_{current.tm_year}_{current.tm_hour}_{current.tm_min}_{current.tm_sec}_{str(dup)}.jpg'
		dup = dup + 1
	cv.imwrite(outputPath,cv.cvtColor(im,cv.COLOR_RGB2BGR))
	root = tk.Tk()
	root.title('Saving')
	tk.Label(root,text=f'Saved Output to {outputPath}',font=("Courier",12)).pack()
	root.after(2000,root.destroy)
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

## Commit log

2022-09-29 Ported from Google Drive
    [DoPro Schematic.SchDoc, DoPro.PrjPcb]
2022-09-29 Stopped tracking Altium files (on Google Drive)
    [DoPro Schematic.SchDoc, DoPro.PrjPcb]
2022-09-29 Revert "Stopped tracking Altium files (on Google Drive)"
    This reverts commit b4a3ebbf6f911ba53ffa554509e24e783c736619.
    [DoPro Schematic.SchDoc, DoPro.PrjPcb]
2022-09-29 Update schematics + libraries
    [DoPro Schematic.SchDoc, DoPro.PrjPcb]
2022-09-29 Update Zaya Schematic Library.SchLib
2022-09-29 Updated project structure
    [DoPro Schematic.SchDoc, DoPro.PrjPcb]
2022-09-29 Updated project structure (again)
    [DoPro Schematic.SchDoc]
2022-10-06 Added Power Button
    [DoPro Schematic.SchDoc]
2022-10-06 Added RPI LED status (on/off) and power delivery
    Also added some symbols to the schematic library
    [DoPro Schematic.SchDoc]
2022-10-18 Added power delivery protections and organized schematic
    [DoPro Schematic.SchDoc]
2022-10-19 Fixed the FSM sudden power off issue
    [cvfsm.py]
2022-10-19 Added flash LED and finalized component selection
    Need to add ADC for battery voltage monitoring
    [DoPro Schematic.SchDoc]
2022-10-27 Switched to lithium ion battery source and changed power delivery to boost converter
    [DoPro Schematic.SchDoc, DoPro.PrjPcb]
2022-10-28 Finished ADC wiring
    [DoPro Schematic.SchDoc]
2022-10-28 Update designators
    [DoPro Schematic.SchDoc]
2022-10-28 Added filtering cap to ADC input
    [DoPro Schematic.SchDoc]
2022-11-08 Added Calibration Module
2022-11-16 DoPro PCB Project Rev.A Complete
    [DoPro BOM.xlsx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]
2023-02-07 Updated Calibration and FSM
2023-02-07 Added initial adc code
2023-02-07 Commited Battery Voltage on Pi ADC
2023-02-09 REV.B with new boost converter IC
    [DoPro BOM.xlsx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]
2023-02-10 Added sample.csv
    [sample.csv]
2023-02-10 Added voltage.csv to not track
2023-02-14 Chganged to actual PCB inputs
2023-02-26 Added Test Calibration set, finished MATLAB calibration
2023-03-02 updated heatmap, custom algs
2023-03-05 ADAS SGBM mapping
    [BM.xlsx, SGBM.xlsx, SGBM_ADAS.xlsx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]
2023-03-07 Again, Massive Update to the FSM. ADAS is good. selector good, 3D reconstruction good/
    [SGBM.xlsx, SGBM_ADAS.xlsx]
2023-03-08 Fixed Monitor battery
2023-03-08 PUshed again
    [voltage_382023_3_31_5.csv]
2023-03-09 Added old voltage metric to plot
    [oldVoltageMetric.xlsx, voltage_382023_3_31_5.csv]
2023-03-09 pushed Battery Metric
    [18650-Powered_RPI_4_-_Sheet1.csv]
2023-03-09 Modified battery metric, made it look better
2023-03-11 Mesh visualization is more appealing
    [cup.stl]
2023-03-16 change button UI, sel1 toggles left and right, sel2 settings
2023-03-17 CAD models
    [Back_Plate.stl, Battery_Holder.stl, Battery_Holder_Lock.stl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]
